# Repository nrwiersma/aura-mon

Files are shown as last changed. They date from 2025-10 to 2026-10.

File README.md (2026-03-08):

<picture>
  <source media="(prefers-color-scheme: dark)" srcset="http://svg.wiersma.co.za/github/project.v2?title=aura mon&tag=energy%20data%20logger&mode=dark">
  <source media="(prefers-color-scheme: light)" srcset="http://svg.wiersma.co.za/github/project.v2?title=aura mon&tag=energy%20data%20logger">
  aura
</picture>

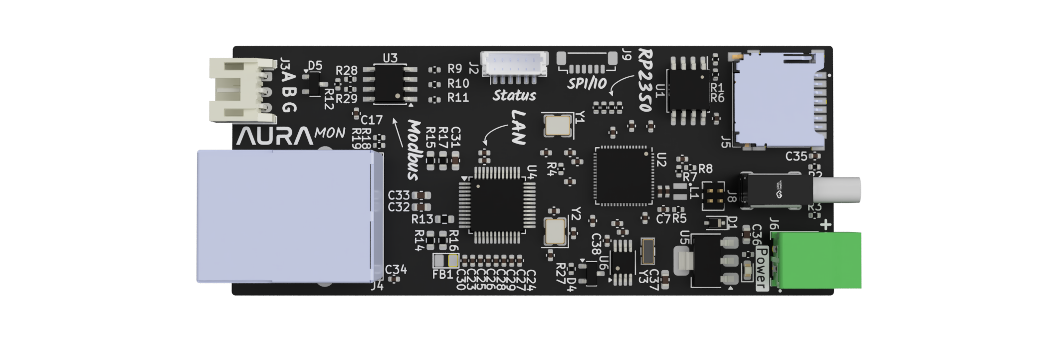
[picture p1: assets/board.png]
board image





`Aura Mon` is an RP2350-based energy data logger built around the tiny [SPM01](https://www.bituo-technik.com/product/spm01-flexible-1pn-63a/) Modbus meter. It samples power data over RS485, stores it on an SD card, and serves a local HTTP API and web UI over Ethernet.

## At a glance

* RP2350 microcontroller
* Modbus RTU over RS485 (SPM01)
* Ethernet for reliable network connectivity
* SD card logging and static web UI hosting
* RTC for timestamped data
* HTTP API with OTA updates and metrics

## System overview

system diagram

## Data flow

data flow

## Why

The goal of this project is to create a reliable and easy-to-use energy data logger that can be used to monitor energy consumption in a home or small business. The SPM01 is a very affordable energy meter that can measure voltage, current, power, energy, and power factor while fitting in tight electrical panels.

## Quick start

1. Assemble the board and connect the SPM01 to the RS485 terminals.
2. Insert an SD card (required for logging).
3. Power the board with a regulated 5V supply on the screw terminals (or via USB-C with the jumper fitted for testing).
4. Connect Ethernet and find the device IP via your router's DHCP lease table.
5. Open `http://<device-ip>` to view the UI and use the API.

## Firmware

The firmware lives in `firmware/` and is written in C++ using the Arduino framework.

* Build/flash instructions: `firmware/FIRMWARE.md`
* HTTP API reference: `firmware/API.md`

### API highlights

* `GET /status` for live readings and runtime stats.
* `GET /energy` for CSV data export.
* `GET /logs` for log streaming.
* `GET`/`POST /config` for device configuration.
* `POST /ota` for firmware updates.
* `GET /metrics` for Prometheus-style metrics.

## Powering

The board can be powered using an external 5V power supply connected to the screw terminals. For testing purposes, it can also be powered via USB-C after connecting the onboard jumper.

## Safety

> [!WARNING]
> This project interfaces with mains-connected equipment. Only install it if you are qualified and follow local electrical safety requirements.

## Project status

The firmware and hardware are still in development and are only tested on the author's hardware. Expect rough edges and please report issues or improvements.

## Changelog

#### v0.1.0

* Initial schematic and board
* Initial firmware with basic functionality to read from the SPM01 and store data on the SD card

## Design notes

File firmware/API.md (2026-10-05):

# AuraMon HTTP API

This document describes the HTTP endpoints exposed by the firmware. All endpoints are served by the device's embedded web server over HTTP.

## Endpoint index

- [`GET /config`](#get-config)
- [`POST /config`](#post-config)
- [`GET /status`](#get-status)
- [`GET /energy`](#get-energy)
- [`POST /device/action`](#post-deviceaction)
- [`GET /logs`](#get-logs)
- [`POST /logs/trunc`](#post-logstrunc)
- [`POST /ota`](#post-ota)
- [`POST /ota/public`](#post-otapublic)
- [`GET /metrics`](#get-metrics)
- [`GET /readyz`](#get-readyz)
- [`GET /livez`](#get-livez)
- [`GET /<path>` (static files)](#get-path-static-files)

## Base

- Base URL: `http://<device-ip>`
- Auth: none
- CORS: enabled

## Common responses

- `200 OK` for successful JSON/plain responses.
- `204 No Content` when there is nothing to return.
- `400 Bad Request` for invalid parameters or invalid JSON.
- `404 Not Found` when a resource does not exist.
- `405 Method Not Allowed` for disallowed methods on static files.
- `408 Request Timeout` when the SD card mutex cannot be acquired.
- `409 Conflict` when a device action is already pending.
- `500 Internal Server Error` for unexpected errors.
- `505 HTTP Version Not Supported` when chunked responses are not available.

## Endpoints

### `GET /config`

Returns the current configuration as JSON.

- Response content type: `application/json`

Example response (shape):
```json
{
  "format": 1,
  "network": {
    "hostname": "aura-mon",
    "ip": "192.168.0.0",
    "gateway": "192.168.0.1",
    "mask": "255.255.255.0",
    "dns": "8.8.8.8"
  },
  "devices": [
    {
      "enabled": true,
      "address": 1,
      "name": "test1",
      "calibration": 1.0,
      "reversed": false
    }
  ]
}
```

### `POST /config`

Updates the configuration. The request body must be JSON.

- Request content type: `application/json`
- Response content type: `text/plain`

Possible error responses:
- `{"error":"No data provided"}`
- `{"error":"Invalid JSON"}`
- `{"error":"Invalid configuration","reason":"..."}`

Example request:
```bash
curl -X POST http://<device-ip>/config \
  -H 'Content-Type: application/json' \
  -d '{"format":1,"network":{"hostname":"aura-mon"},"devices":[]}'
```

### `GET /status`

Returns runtime status and device data.

- Response content type: `application/json`

Response fields:
- `version` string.
- `stats` object: `startTime`, `currentTime`, `runSeconds`, `heapFree`.
- `devices` array: each entry has `name`, `volts`, `amps`, `pf`, `hz`.
- `datalog` object: `firstRev`, `lastRev`, `interval`.
- `network` object: `hostname`, `ip`, `gateway`, `subnet`, `dns`, `mac`.
- `uploaders` array: one entry per configured, enabled uploader (see `POST /config`'s
  `uploaders`), each with:
  - `id`, `type` - matches the uploader's config entry.
  - `state` - `"build"`, `"post"`, or `"wait"`; which step of its request cycle it's
    currently in.
  - `lastSentTS` - datalog timestamp up to which data has been successfully uploaded.
  - `lagSeconds` - how far `lastSentTS` is behind the datalog's most recent record; grows
    while the network is down or the remote endpoint is failing, and shrinks once it
    catches back up.
  - `successTotal`, `failureTotal` - lifetime (since boot) counts of completed requests.
  - `consecutiveFailures` - resets to 0 on the next success; useful for alerting on a
    stuck/misconfigured uploader without tripping on an isolated blip.
  - `lastSuccessAt`, `lastAttemptAt` - unix timestamps, `0` if never.
  - `lastHttpStatus` - HTTP status of the last completed request; `-1` if the last attempt
    failed before a response was received (e.g. could not open/send), `0` if no request has
    completed yet.

### `GET /energy`

Returns energy data as CSV in a chunked response.

- Response content type: `text/plain` (CSV)

Query parameters:
- `start` (required): unix timestamp (seconds).
- `end` (optional): unix timestamp (seconds), defaults to `now`.
- `interval` (optional): seconds, defaults to `5`.

Behavior:
- `start`, `end`, and `interval` are rounded down to the nearest datalog interval.
- If `start >= end` or `interval == 0`, returns `400`.
- Response is capped to 100 rows (`end = start + interval * 100`).
- Returns `204` if there is no data, no enabled devices, or `start` is beyond the last timestamp.

CSV columns:
- `timestamp`
- `Hz`
- For each enabled device: `<name>.V`, `<name>.A`, `<name>.W`, `<name>.Wh`, `<name>.PF`

Example:
```bash
curl "http://<device-ip>/energy?start=1730000000&end=1730003600&interval=60"
```

### `POST /device/action`

Queues a device action.

- Request content type: `application/json`
- Response content type: `application/json`

Request body:
```json
{
  "action": "locate" | "assign",
  "address": 1
}
```

Notes:
- `address` must be in `1..15`.
- Returns `202` with `{"status":"queued"}` when accepted.
- Returns `409` if another action is already pending.

### `GET /logs`

Streams the message log file from the SD card.

- Response content type: `text/plain`
- Query parameters:
  - `start` (optional): byte offset to start streaming from.
  - `limit` (optional): maximum number of bytes to stream.
- Returns `204` when `start` is at or beyond the end of the file, or when `limit=0`.
- Returns `400` for an invalid `start` or `limit` value.
- Returns `404` if the log file is missing.

Example:
```bash
curl "http://<device-ip>/logs?start=1024&limit=4096"
```

### `POST /logs/trunc`

Truncates the message log by keeping content from the last `**** RESTART ****` marker to the end of the file.

- Response content type: `text/plain`
- Uses a temp file and replace flow (`temp -> log`) so truncation is resilient to partial writes.
- Returns `204` on success.
- Returns `404` if the log file is missing.
- Returns `408` if the SD card mutex cannot be acquired.
- Returns `500` for file IO/rename failures.

Example:
```bash
curl -X POST http://<device-ip>/logs/trunc
```

### `POST /ota`

Firmware update via multipart upload.

- Request content type: `multipart/form-data`
- Form field name: `firmware`

Responses:
- `204` on success (device reboots).
- `500` on failure with `{"error":"Update failed","code":<code>}`.

Example:
```bash
curl -X POST http://<device-ip>/ota \
  -F 'firmware=@firmware.bin'
```

### `POST /ota/public`

Upload a static file to the SD card `public/` directory.

- Request content type: `multipart/form-data`
- Form field name: `file`
- Filename must not be empty and must not contain `/` or `\\`.

Responses:
- `204` on success.
- `400` on invalid field name or filename.
- `408` if the SD card mutex cannot be acquired.
- `500` on write failure.

Example:
```bash
curl -X POST http://<device-ip>/ota/public \
  -F 'file=@index.html'
```

### `GET /metrics`

Prometheus-style metrics in text format.

- Response content type: `text/plain`

Exposed metrics:
- `auramon_modbus_errors_total` (counter)
- `auramon_collect_time_seconds_total` (counter)
- `auramon_collect_time_seconds_avg` (gauge)
- `auramon_datalog_read_io` (counter)
- `auramon_datalog_write_io` (counter)
- `auramon_datalog_write_time_seconds_total` (counter)
- `auramon_datalog_cache_hit` (counter)
- `auramon_datalog_write_errors_total` (counter)
- `auramon_datalog_queue_depth` (gauge)
- `auramon_datalog_queue_full_total` (counter)
- `auramon_datalog_records_dropped_total` (counter)
- `auramon_uploader_requests_total{id,type}` (counter) - total successful upload requests.
- `auramon_uploader_errors_total{id,type}` (counter) - total failed upload attempts (network
  or non-2xx response).
- `auramon_uploader_consecutive_failures{id,type}` (gauge) - current run of consecutive
  failed attempts, reset on the next success.
- `auramon_uploader_lag_seconds{id,type}` (gauge) - how far behind the uploader is from the
  most recently logged record.
- `auramon_uploader_last_success_timestamp_seconds{id,type}` (gauge) - unix timestamp of the
  last successful upload, `0` if never.
- `auramon_uploader_last_http_status{id,type}` (gauge) - HTTP status of the last completed
  request; `-1` if it failed before a response was received, `0` if none has completed yet.

### `GET /readyz`

Returns `200` with an empty body.

### `GET /livez`

Returns `200` with an empty body.

### `GET /<path>` (static files)

Any other `GET` request serves files from the SD card `public/` directory.

Behavior:
- `/` maps to `/index.html`.
- If a `.gz` version exists, it is served with `Content-Encoding: gzip`.
- Directories return `403`.
- Unknown paths return `404`.

Common content types:
- `.html` -> `text/html`
- `.css` -> `text/css`
- `.js` -> `application/javascript`
- `.json` -> `application/json`
- `.png` -> `image/png`
- `.jpg`/`.jpeg` -> `image/jpeg`
- `.svg` -> `image/svg+xml`

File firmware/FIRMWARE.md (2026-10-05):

# Firmware Architecture

The firmware runs on an RP2040 dual-core microcontroller. Each core has a dedicated role: **Core 0 (Control Plane)** handles networking, the web API, and system housekeeping, while **Core 1 (Data Plane)** handles real-time energy data collection and storage.

```mermaid
flowchart TD
    subgraph BOOT["Boot Sequence (Core 0)"]
        direction TB
        B1[Init Serial & LEDs] --> B2[Init SD Card]
        B2 --> B3[Init RTC & set system time]
        B3 --> B4[Load config & sync device info]
        B4 --> B5[Init Ethernet / W5500]
        B5 --> B6[Init Datalog]
        B6 --> B7[Init Modbus RTU / RS-485]
        B7 --> B8[Setup Web API & HTTP server]
        B8 --> B9[Register tasks & signal Core 1 via FIFO]
    end

    subgraph C0["Core 0 — Control Plane"]
        direction TB
        L0A[server.handleClient\nServe HTTP API requests]
        L0B[handleButtonPress\nDebounce button & queue addDeviceFromButton]
        L0C[c0Queue.runNextTask]

        T0A["⏱ timeSync  · 60s\nNTP sync, update RTC\nReboot after 42 days"]
        T0B["⏱ checkEthernet  · 1s\nMonitor link & IP\nReboot after 60 min offline"]
        T0C["⏱ syncState  · 1s\nCheck SD & Ethernet\nUpdate LED  🔴 · 🟠 · 🟢"]
        T0D["▶ addDeviceFromButton  · on demand\nAssign free Modbus address\nSave config to SD"]
        T0E["⏱ writeLogData  · 100ms idle\nPop queued records\nWrite record to SD datalog"]
        T0F["⏱ syncUploaders  · 1s\nInstantiate/stop Uploader objects\nfrom config.json's uploaders[]"]
        T0G["▶ Uploader.dispatch  · per uploader\nBuild → Post → Wait state machine\nAsyncHTTP (RPAsyncTCP), non-blocking"]

        L0C --> T0A & T0B & T0C & T0D & T0E & T0F & T0G
    end

    subgraph C1["Core 1 — Data Plane"]
        direction TB
        S1[Wait for FIFO signal] --> S2[initLogData & start watchdog 800ms]

        L1A["collect()  · each cycle\nPoll all devices over Modbus RTU\nDecode V, A, W, VA, PF, Hz\nUpdate metrics"]
        L1B[c1Queue.runNextTask\nKick watchdog]

        T1A["⏱ logData  · per interval\nAccumulate Wh / VAh / VoltHrs\nQueue record for Core 0"]
        T1B["⏱ syncDevices  · 1s\nSync device info, actions\n& live readings via mutexes"]
        T1C["⏱ deviceActionTask  · 1s\nLocate: flash device LED\nAssign: set Modbus address"]

        S2 --> L1A --> L1B
        L1B --> T1A & T1B & T1C
    end

    BOOT --> C0 & C1
```

## Core Responsibilities

| | Core 0 | Core 1 |
|---|---|---|
| **Main loop focus** | HTTP request handling & button debounce | Energy data collection via Modbus (1 s cycle) |
| **Scheduled tasks** | `timeSync`, `checkEthernet`, `syncState`, `writeLogData`, `syncUploaders`, one `Uploader::dispatch` per configured uploader | `logData`, `syncDevices`, `deviceActionTask` |
| **On-demand tasks** | `addDeviceFromButton` (button press) | — |
| **Watchdog** | — | 800 ms watchdog, kicked each collection cycle |
| **LED control** | `syncState` sets colour, `Ticker` blinks at 1 Hz | — |

## Task Priorities (higher = runs first when multiple tasks are due)

| Task | Core | Priority |
|---|---|---|
| `logData` | 1 | 7 |
| `syncDevices` | 1 | 6 |
| `writeLogData` | 0 | 6 |
| `timeSync` | 0 | 5 |
| `deviceActionTask` | 1 | 5 |
| `checkEthernet` | 0 | 5 |
| `syncState` | 0 | 4 |
| `syncUploaders` | 0 | 3 |
| `Uploader::dispatch` (each uploader) | 0 | 2 |

## Data Log Record Queue

`logData` on Core 1 accumulates energy readings, but does not touch the SD card. Once an
interval completes, the record is copied onto a fixed size FIFO queue (`logQueue`, 8 records)
and `writeLogData` on Core 0 pops it and writes it to the data log. This keeps SD card IO,
which can block for tens of milliseconds, off the collection core.

- If the queue is full, `logData` retries on the next cycle rather than dropping the record,
  so the log slips but no data is lost.
- Records are queued and written in timestamp order, which the data log requires.
- A record that fails to write is retried up to 5 times, then dropped so it cannot block the
  records behind it.
- On a controlled reboot, the queue is drained before the data log is closed.

## Uploaders (InfluxDB2/3, Home Assistant, ...)

`Uploader` (`src/uploader/uploader.h/.cpp`) is the base class for Core0 tasks that push data
log records to a remote service. `UploaderConfig` (`src/config.h`) is its persisted,
user-editable counterpart: an entry in config.json's `uploaders` array (`id`, `type`,
`enabled`, `interval`, and a free-form `settings` object whose schema is owned by the
concrete uploader type). `uploader_registry.cpp` is the only code that creates or stops
`Uploader` instances, reconciling `uploaderConfigs[]` with live instances whenever the config
changes (`syncUploaders`, mirroring `syncDevices`'s `devicesChanged` pattern) — concrete
uploader types are registered there as they are implemented.

- `InfluxDB2Uploader` (`src/uploader/influxdb2_uploader.h/.cpp`, `type: "influxdb2"`) writes
  one line-protocol point per enabled, named device per interval (plus one for mains
  frequency) to an InfluxDB 2.x bucket via `/api/v2/write`. Settings: `url`, `org`, `bucket`,
  `token`, optional `measurement` (default `"aura-mon"`). Its settings parsing and
  line-protocol formatting are pulled out into `src/uploader/influxdb2_format.h/.cpp`, which
  has no HTTP/xbuf/data-log dependencies and is covered by native unit tests
  (`test/test_influxdb2`); the surrounding HTTP/data-log glue in `influxdb2_uploader.cpp`
  follows `Uploader` itself in being hardware-only and not natively tested.
- `HomeAssistantUploader` (`src/uploader/homeassistant_uploader.h/.cpp`, `type:
  "homeassistant"`) posts one JSON payload per interval - mains frequency plus one entry per
  enabled, named device - to a Home Assistant webhook (`<url>/api/webhook/<webhook_id>`).
  Settings: `url`, `webhook_id`. Unlike InfluxDB2's point-per-reading model, the payload
  carries the whole interval as a single object: `{"ts", "hz", "devices": [{"name", "volts",
  "amps", "watts", "wh", "pf"}, ...]}`, where `wh` is the energy consumed during that interval
  (not a running total), matching the existing pull-based `/energy` semantics so the Home
  Assistant component can accumulate it itself. Its settings parsing and payload building are
  pulled out into `src/uploader/homeassistant_format.h/.cpp` (no HTTP/xbuf/data-log
  dependencies, covered by native unit tests in `test/test_homeassistant`); the hardware glue
  in `homeassistant_uploader.cpp` serializes the built `JsonDocument` straight into the
  request body via ArduinoJson's `Print`-based `serializeJson`.

Each `Uploader` runs as its own lowest-priority Core0 task, built on `lib/AsyncHTTP`
(`asyncHTTPrequest` ported onto `RPAsyncTCP`) so a request in flight never blocks anything
else: `dispatch()` is a non-blocking `Build → Post → Wait` state machine that returns almost
immediately every tick.

- **No data is lost on a network outage.** The data log already retains up to ~180 days of
  history on SD; an uploader only tracks how far it has gotten (`_lastSentTS`), persisted to
  `aura-mon/uploaders/<id>.state`. While the link is down (`eth.isLinked()`/`connected()`
  checked every `Build`), the uploader simply waits and retries — it never advances past data
  it hasn't confirmed as sent, and a reboot resumes from the saved position rather than
  replaying the whole log or skipping ahead.
- **Never blocks SD or networking.** Scheduled at the lowest Core0 priority (below
  `writeLogData`, `checkEthernet`, and `syncState`), so it only runs when nothing more
  important is due, and each state transition does O(1) non-blocking work.
- **Stopping is self-serviced.** The task queue has no cancel primitive, so a disabled or
  misconfigured uploader is told to stop (`requestStop()`); the registry drops its own
  pointer immediately, and the instance deregisters and frees itself (`delete this; return
  0;`) the next time its already-scheduled task runs.
- **Health is observable.** Each `Uploader` tracks success/failure counts, consecutive
  failures, last HTTP status, and last success/attempt timestamps (`recordResult()`,
  read-only accessors on `Uploader`); `forEachUploader()` (`uploader_registry.h`) lets
  `api.cpp` surface these, plus `lastSentTS`/`lagSeconds` (how far behind the datalog's head
  it is) and its current state machine step, in both `GET /status` (`uploaders` array) and
  `GET /metrics` (`auramon_uploader_*` series, labelled `id`/`type`) — see `API.md`. No
  locking is needed since `dispatch()` and the web server both run on Core0's single
  cooperative loop.

## Hardware Peripherals

| Peripheral | Interface | Used By |
|---|---|---|
| W5500 Ethernet | SPI | Control Plane — HTTP server, NTP, link monitoring |
| RS-485 / Modbus RTU | Serial1 | Data Plane — device polling & address assignment |
| SD Card | SDIO (`sdMu`) | Control Plane — config r/w & datalog writes |
| PCF85063A RTC | I²C / Wire1 | Boot — set system clock |
| LED (Red / Green) | GPIO 10 / 11 | Control Plane — `syncState` sets colour, `Ticker` blinks at 1 Hz |
| Physical Button | GPIO 3 | Control Plane — triggers `addDeviceFromButton` on press |

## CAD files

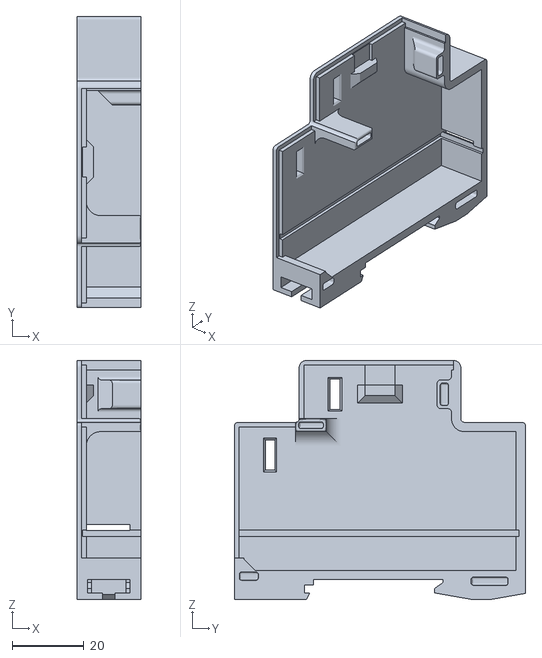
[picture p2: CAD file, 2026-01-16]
models/Base Right.stl
17.9 x 81.0 x 66.5

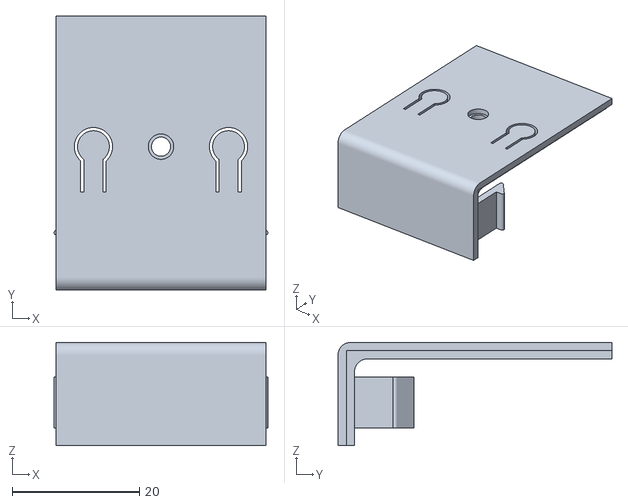
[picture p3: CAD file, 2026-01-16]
models/Face Top.stl
33.5 x 43.0 x 16.2

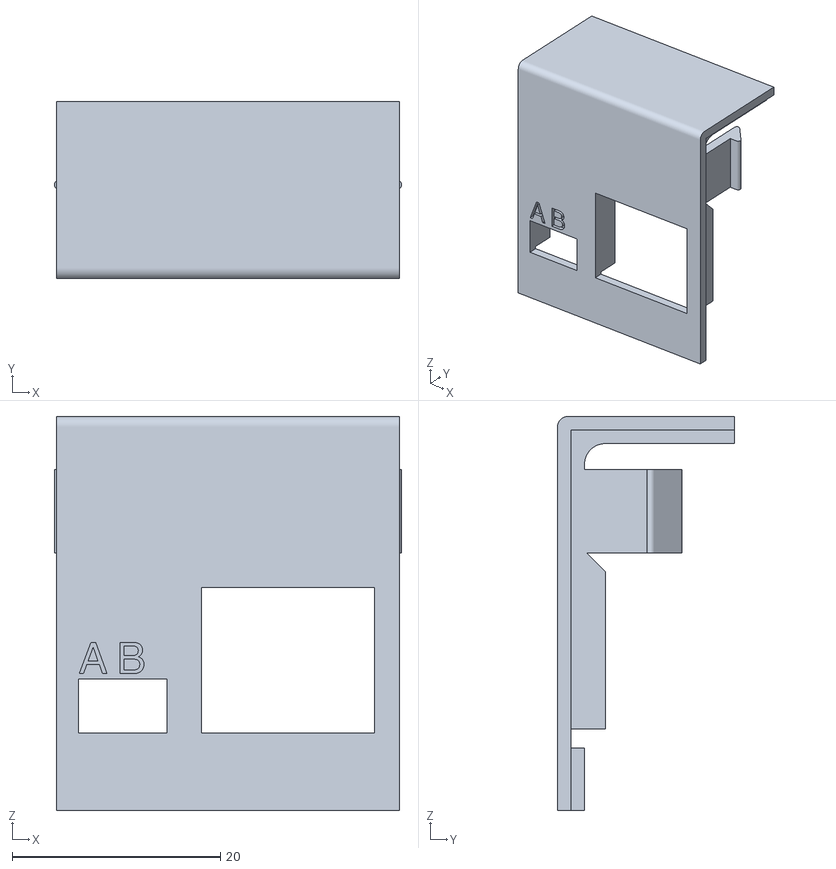
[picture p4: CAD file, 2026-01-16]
models/Face Bottom.stl
33.3 x 17.0 x 37.8

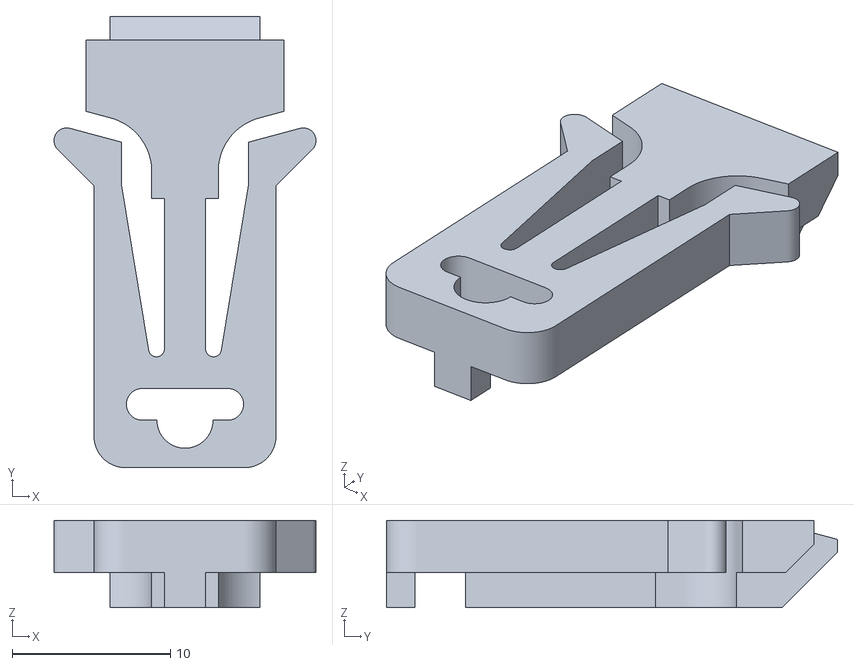
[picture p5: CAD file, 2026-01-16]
models/Clip.stl
16.5 x 28.5 x 5.50

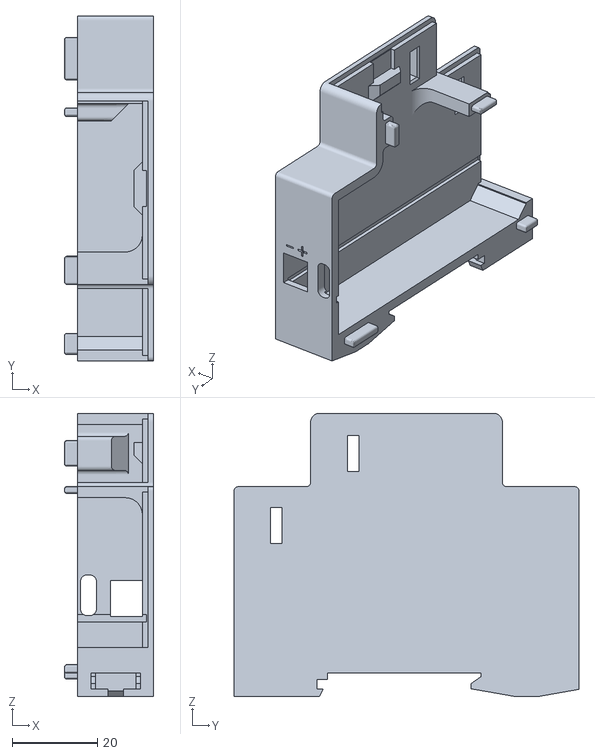
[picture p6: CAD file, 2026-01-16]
models/Base Left.stl
20.9 x 81.0 x 66.5

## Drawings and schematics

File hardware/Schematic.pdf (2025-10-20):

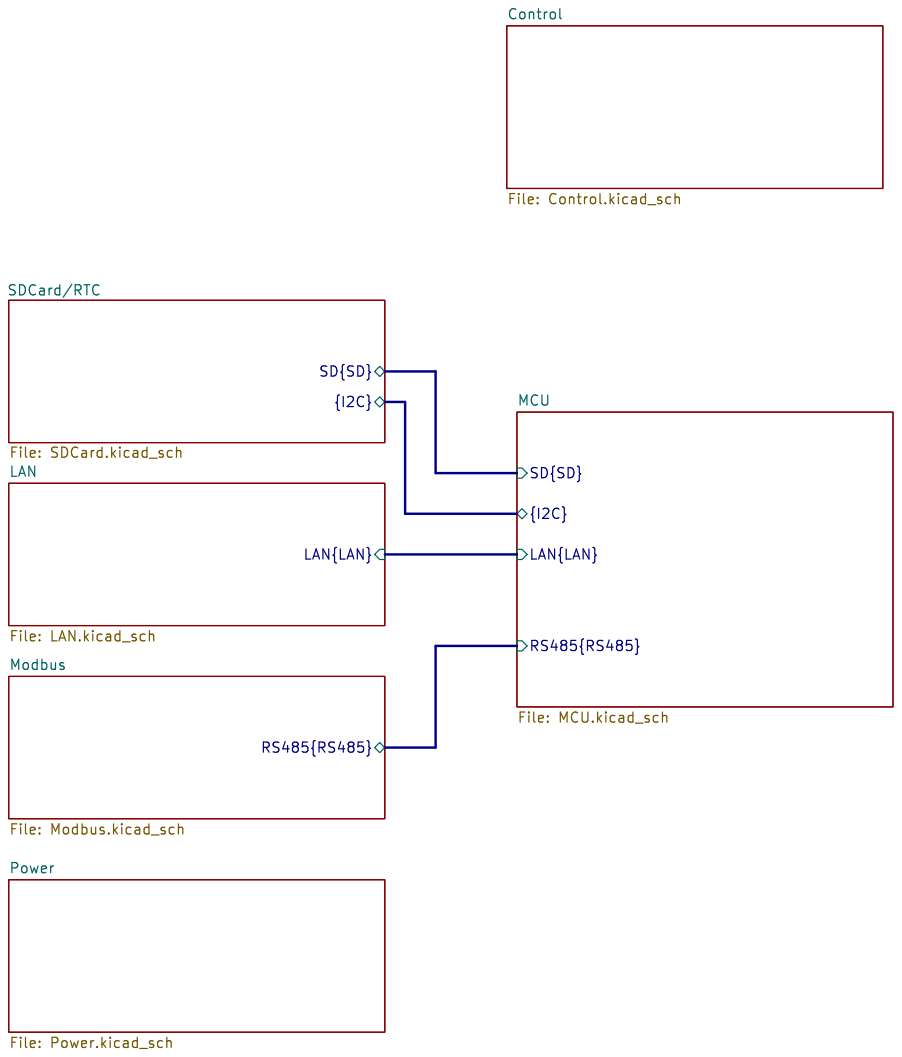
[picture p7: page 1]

File: MCU.kicad_sch Control File: Control.kicad_sch SD{SD}

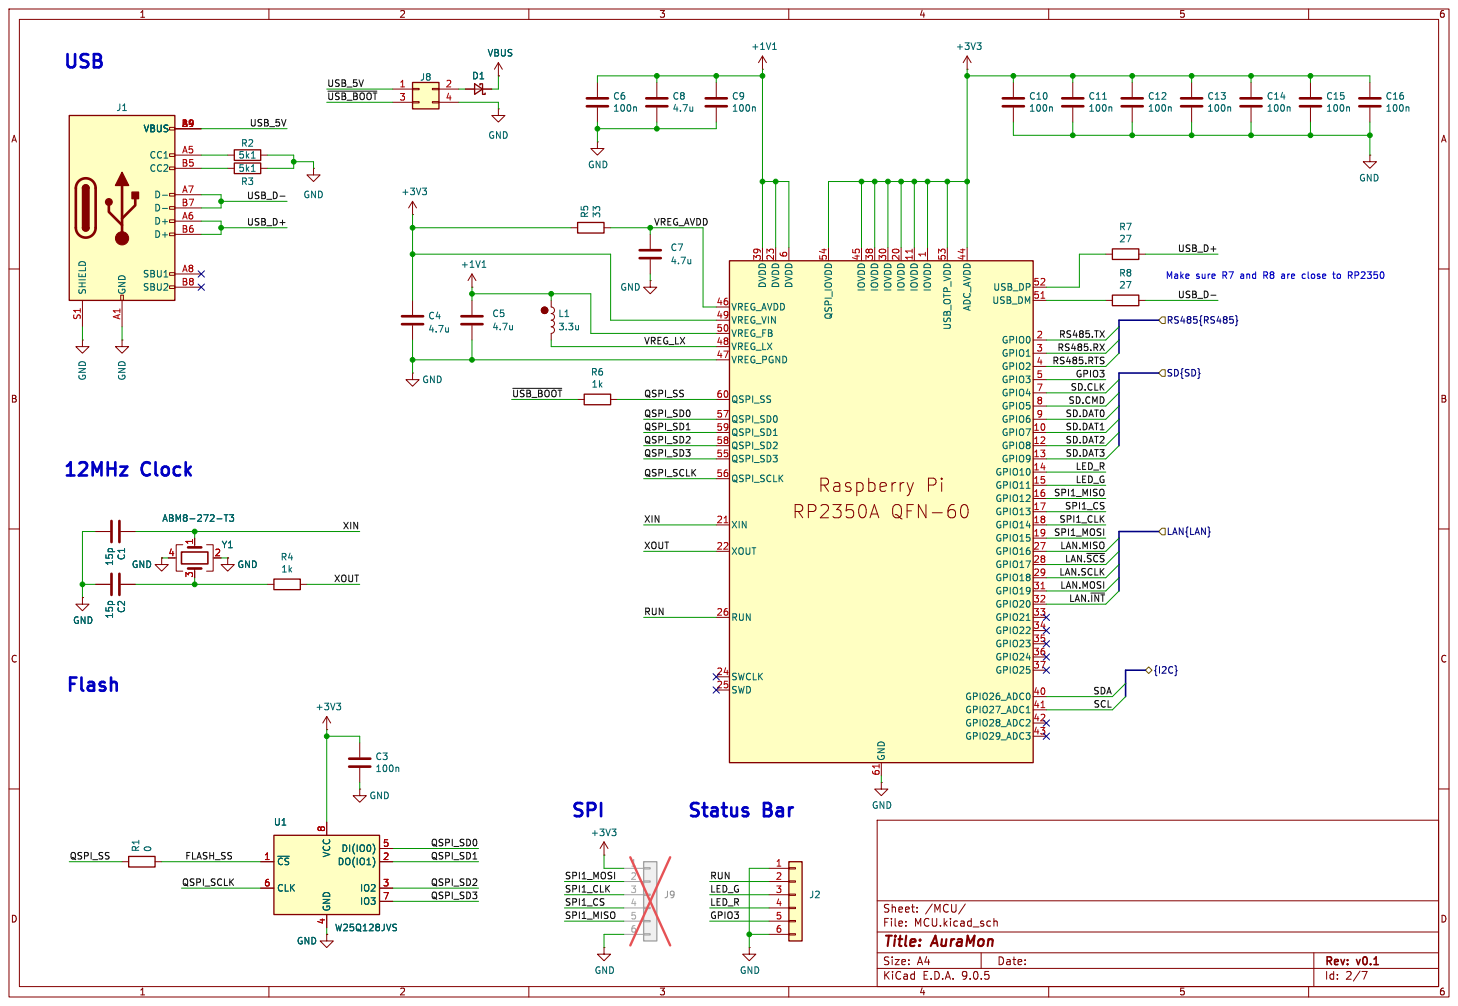
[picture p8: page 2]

6 QSPI_IOVDD 54 IOVDD 45 IOVDD 38 GND 61 IOVDD 30 IOVDD 20 IOVDD 11 IOVDD

SPI1_MOSI LAN.~{SCS} LAN.MISO
LAN.~{INT} SDA

File: MCU.kicad_sch Sheet: /MCU/
Id: 2/7 Title: AuraMon

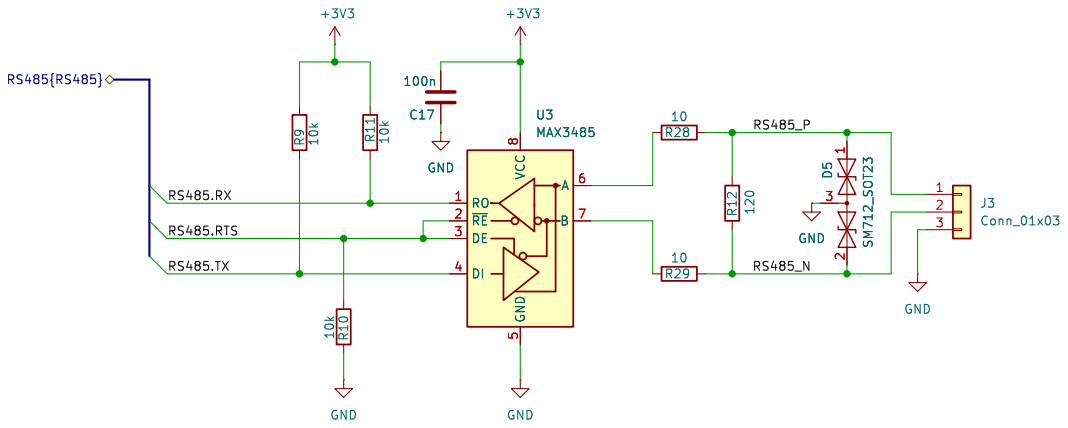
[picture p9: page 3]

2 U3 MAX3485 RO 1 ~{RE} 2 DE 3 DI 4 VCC

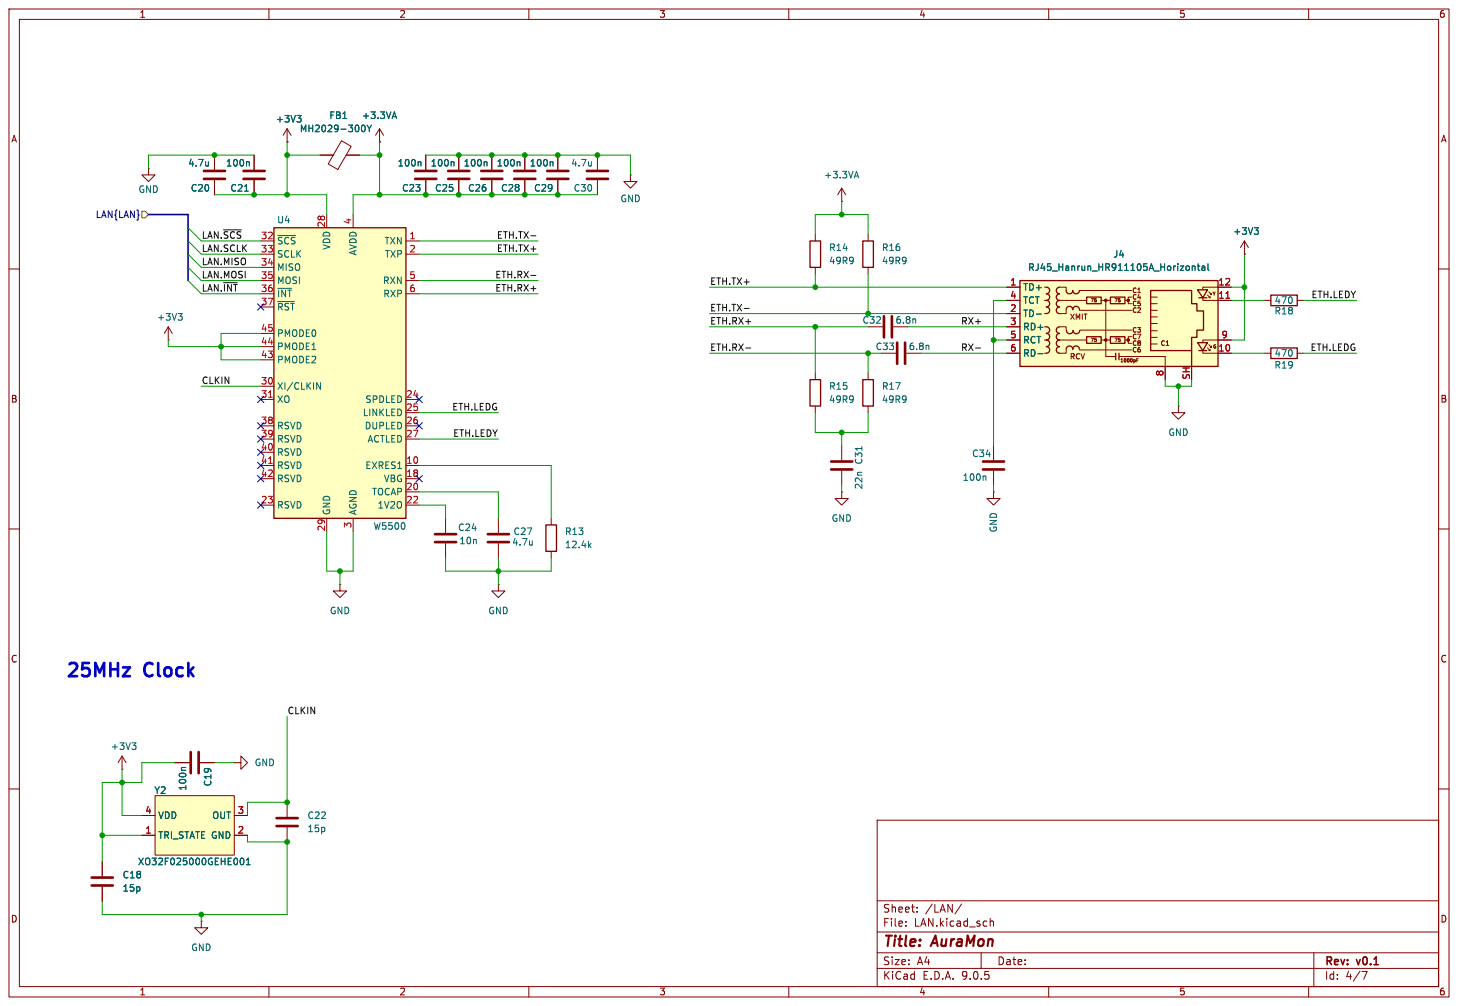
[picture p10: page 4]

LAN.MOSI LAN.~{INT} CLKIN

3 TXN 1 TXP 2 RXN 5 RXP 6 SPDLED 24

ETH.RX+ ETH.LEDY

File: LAN.kicad_sch Sheet: /LAN/
Id: 4/7 Title: AuraMon

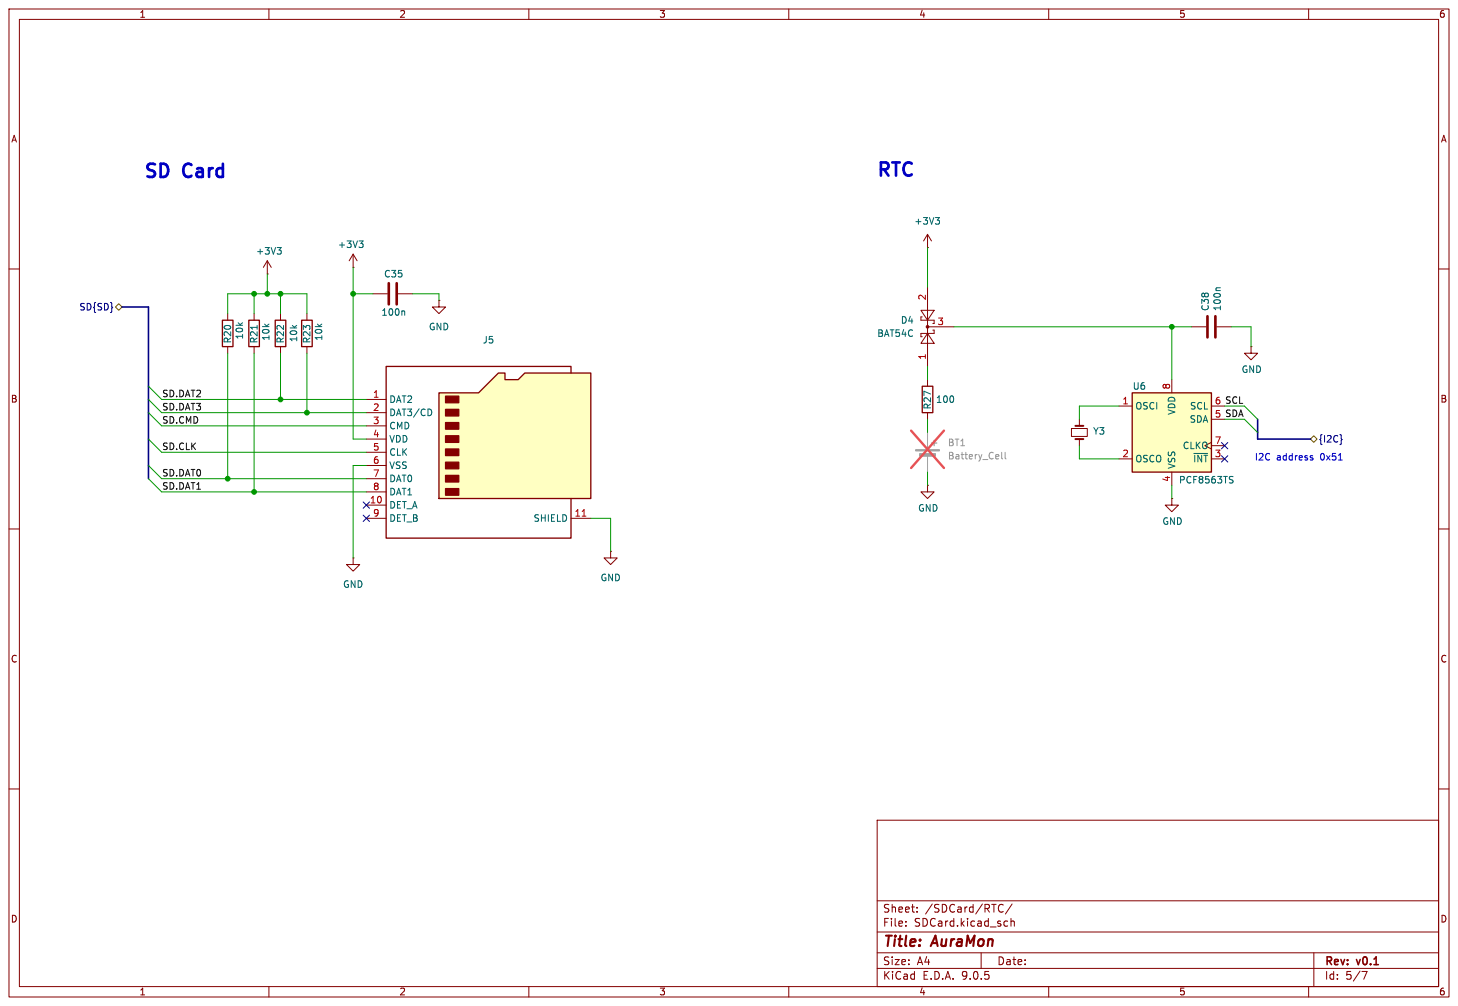
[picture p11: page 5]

4 SCL 6 SDA 5 CLKO 7 ~{INT}3 U6 PCF8563TS GND

File: SDCard.kicad_sch Sheet: /SDCard/RTC/
Id: 5/7 Title: AuraMon

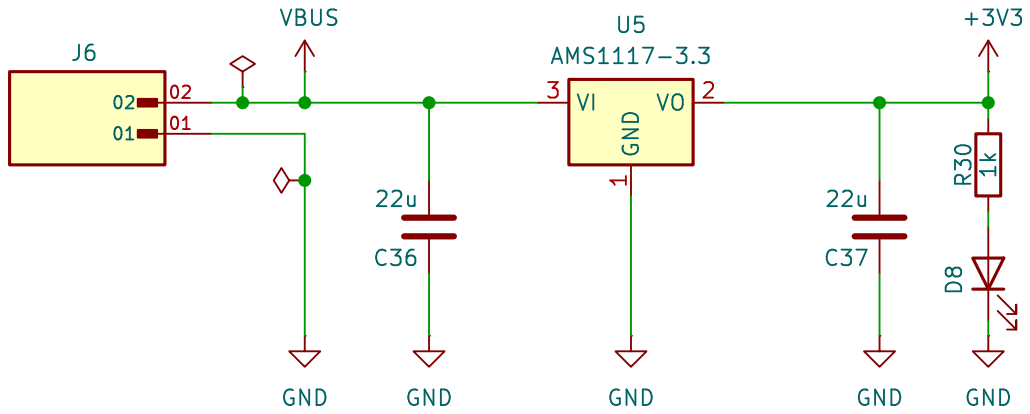
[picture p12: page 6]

File: Power.kicad_sch Sheet: /Power/
Id: 6/7 Title: AuraMon

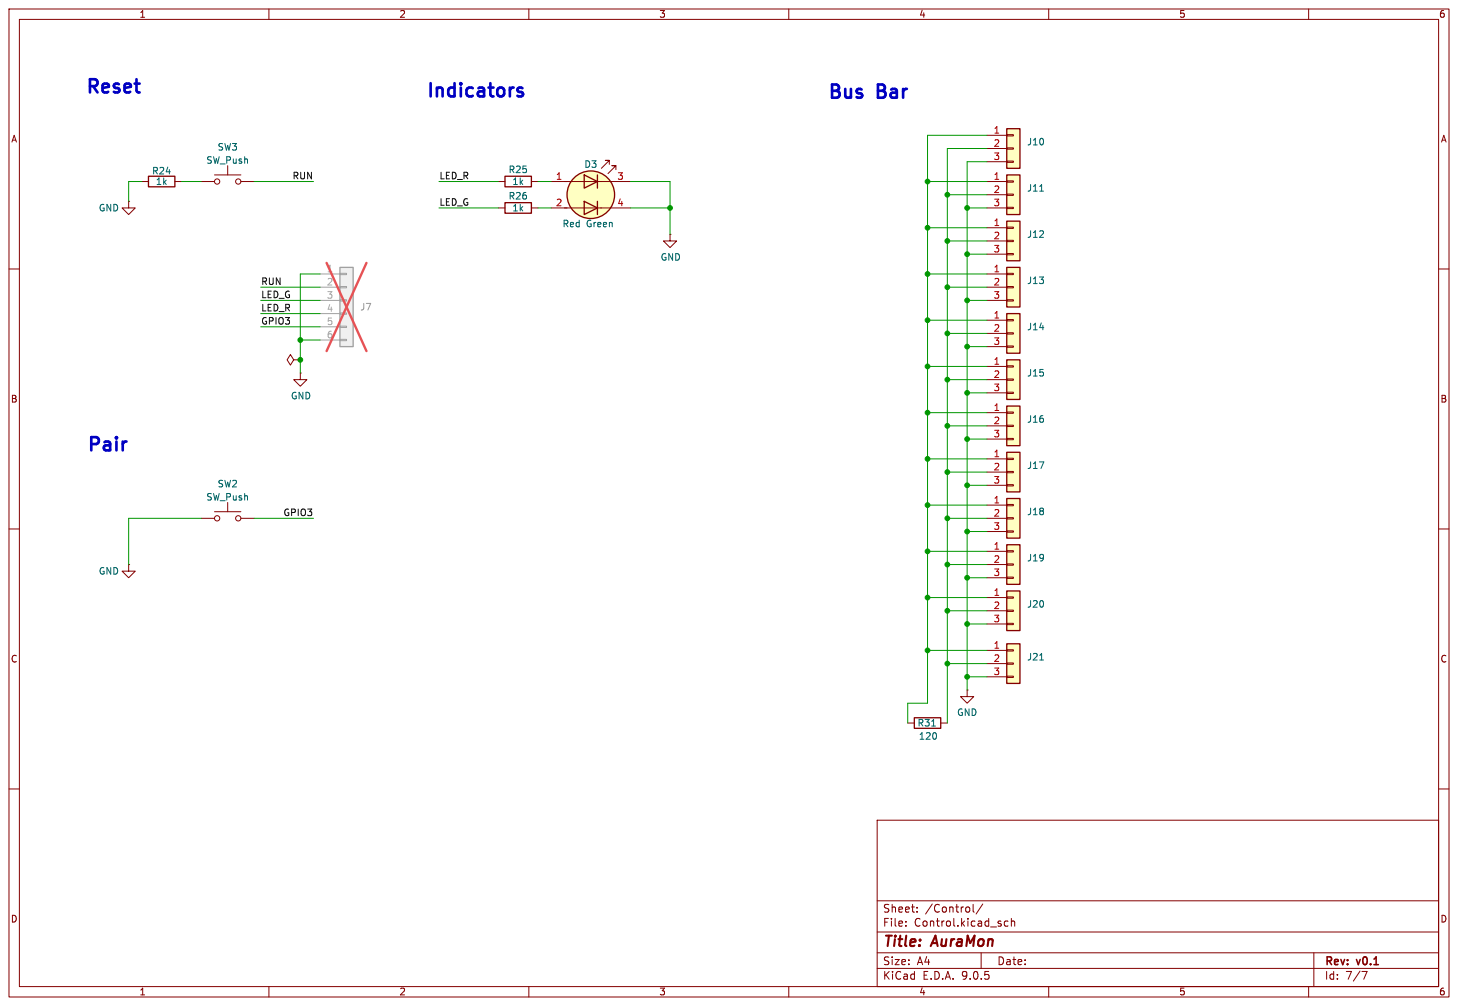
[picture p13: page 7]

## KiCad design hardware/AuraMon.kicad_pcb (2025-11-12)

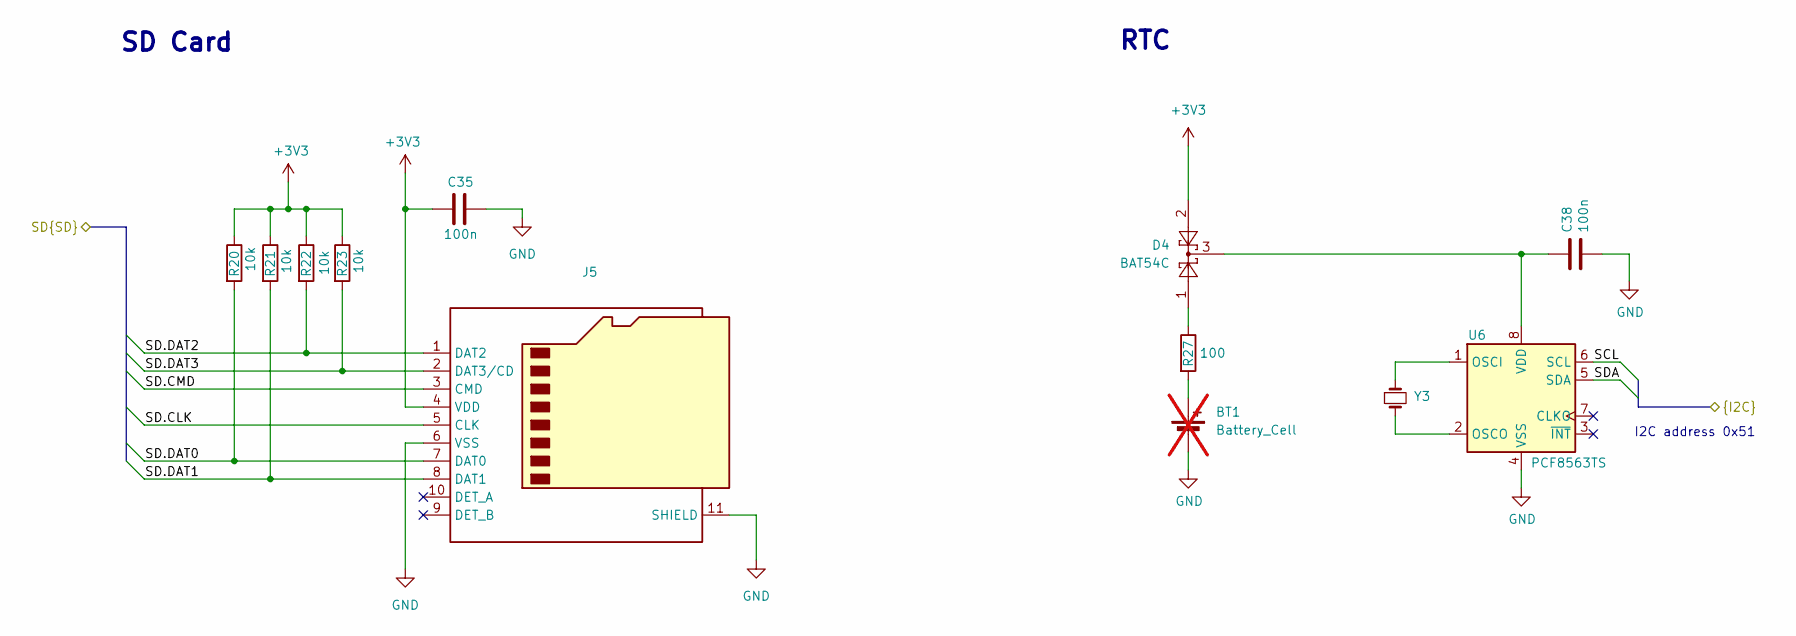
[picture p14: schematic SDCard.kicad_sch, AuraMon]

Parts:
BT1: Battery_Cell; BatteryHolder_Keystone_1060_1x2032; not fitted
C35, C38: 100n; C_0402_1005Metric; MPN CL05B104KO5NNNC; JLCPCB Part # C1525
D4: BAT54C; SOT-23; MPN BAT54C-7-F; JLCPCB Part # C134405
J5: Micro_SD_Card_Det_Hirose_DM3AT; AMPHENOL_1140084168; MPN 114-00841-68; JLCPCB Part # C3195424
R20, R21, R22, R23: 10k; R_0402_1005Metric; MPN RC0402JR-0710KL; JLCPCB Part # C60489
R27: 100; R_0402_1005Metric; MPN RC0402FR-07100RL; JLCPCB Part # C106232
U6: PCF8563TS; MSOP-8_3x3mm_P0.65mm; MPN PCF85063ATT/AJ; JLCPCB Part # C165608
Y3: X321532768KGD2SI; Crystal_SMD_3215-2Pin_3.2x1.5mm; MPN X321532768KGD2SI; JLCPCB Part # C620155

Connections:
+3V3: C35.2, D4.2, J5.4 (VDD), R20.1, R21.1, R22.1, R23.1; also elsewhere on the board
/MCU/SCL: U6.6 (SCL); also elsewhere on the board
/MCU/SD.CLK: J5.5 (CLK); also elsewhere on the board
/MCU/SD.CMD: J5.3 (CMD); also elsewhere on the board
/MCU/SD.DAT0: J5.7 (DAT0), R20.2; also elsewhere on the board
/MCU/SD.DAT1: J5.8 (DAT1), R21.2; also elsewhere on the board
/MCU/SD.DAT2: J5.1 (DAT2), R22.2; also elsewhere on the board
/MCU/SD.DAT3: J5.2 (DAT3/CD), R23.2; also elsewhere on the board
/MCU/SDA: U6.5 (SDA); also elsewhere on the board
GND: BT1.2 (-), C35.1, C38.2, J5.6 (VSS), J5.11 (SHIELD), U6.4 (VSS); also elsewhere on the board
unnamed: BT1.1 (+), R27.2
unnamed: D4.1, R27.1
unnamed: U6.1 (OSCI), Y3.1
unnamed: U6.2 (OSCO), Y3.2
unnamed: C38.1, D4.3, U6.8 (VDD)

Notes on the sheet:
I2C address 0x51
RTC
SD Card

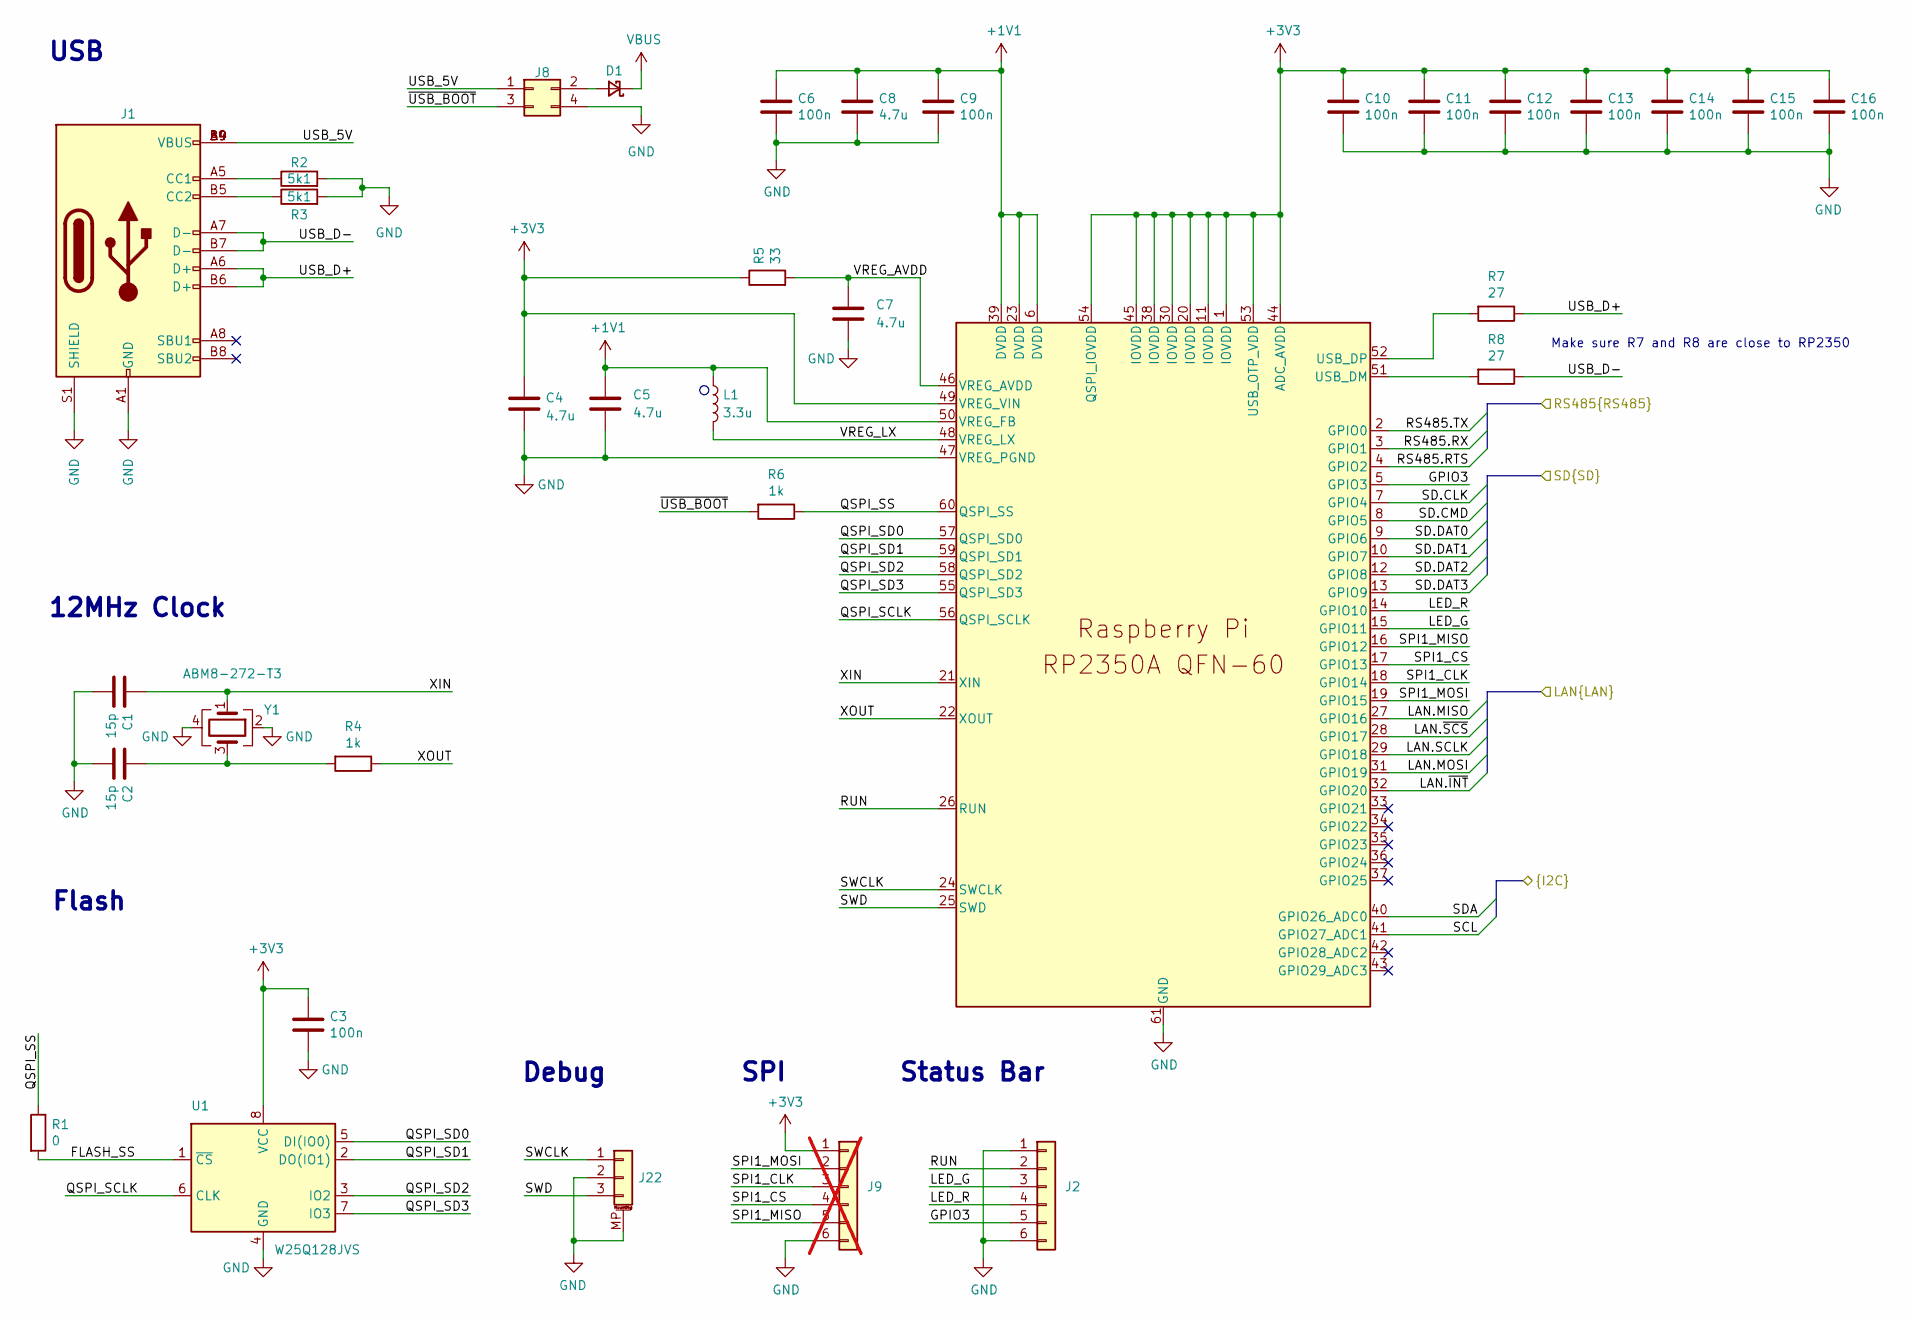
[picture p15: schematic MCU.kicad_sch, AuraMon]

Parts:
C1, C2: 15p; C_0402_1005Metric; MPN CL05C150JB5NNNC; JLCPCB Part # C86285
C3, C6, C9, C10, C11, C12, C13, C14, C15, C16: 100n; C_0402_1005Metric; MPN CL05B104KO5NNNC; JLCPCB Part # C1525
C4, C5: 4.7u; C_0402_1005Metric_small_pads; MPN CL05A475MO5NUNC; JLCPCB Part # C318563
C7, C8: 4.7u; C_0402_1005Metric; MPN CL05A475MO5NUNC; JLCPCB Part # C318563
D1: D_Schottky_Small; D_SOD-323; MPN BAT760-7; JLCPCB Part # C124187
J1: USB_C_Receptacle_USB2.0_16P; USB-C-SMD_TYPEC-305-ACP16H458; MPN TYPEC-305-ACP16H458; JLCPCB Part # C5454943
J2: Conn_01x06; JST_SH_BM06B-SRSS-TB_1x06-1MP_P1.00mm_Vertical; MPN BM06B-SRSS-TB(LF)(SN); JLCPCB Part # C160392
J8: Conn_02x02_Odd_Even; PinHeader_2x02_P1.27mm_Vertical; MPN DW127R-22-04-23; JLCPCB Part # C2935950
J9: Conn_01x06; JST_SUR_BM06B-SURS-TF_1x06-1MP_P0.80mm_Vertical; not fitted
J22: SM03B-SRSS-TB; JST_SH_SM03B-SRSS-TB_1x03-1MP_P1.00mm_Horizontal
L1: 3.3u; L_pol_2016; MPN AOTA-B201610S3R3-101-T; JLCPCB Part # C42411119
R1: 0; R_0402_1005Metric; MPN RC0402JR-070RL; JLCPCB Part # C60485
R2, R3: 5k1; R_0402_1005Metric; MPN RC0402FR-075K1L; JLCPCB Part # C105872
R4, R6: 1k; R_0402_1005Metric; MPN RC0402FR-071KL; JLCPCB Part # C106235
R5: 33; R_0402_1005Metric; MPN RC0402FR-0733RL; JLCPCB Part # C138002
R7, R8: 27; R_0402_1005Metric; MPN RC0402FR-0727RL; JLCPCB Part # C138021
U1: W25Q128JVS; SOIC-8_5.23x5.23mm_P1.27mm; MPN W25Q128JVSIQ; JLCPCB Part # C97521
U2: RP2350A; QFN-60_7X7_RPI; MPN RP2350A; JLCPCB Part # C42411118
Y1: ABM8-272-T3; Crystal_SMD_3225-4Pin_3.2x2.5mm; MPN ABM8-272-T3; JLCPCB Part # C20625731

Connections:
+1V1: C5.1, C6.1, C8.1, C9.1, L1.1, U2.6 (DVDD), U2.23 (DVDD), U2.39 (DVDD), U2.50 (VREG_FB)
+3V3: C3.1, C4.1, C10.1, C11.1, C12.1, C13.1, C14.1, C15.1, C16.1, J9.1, R5.1, U1.8 (VCC), U2.1 (IOVDD), U2.11 (IOVDD), U2.20 (IOVDD), U2.30 (IOVDD), U2.38 (IOVDD), U2.44 (ADC_AVDD), U2.45 (IOVDD), U2.49 (VREG_VIN), U2.53 (USB_OTP_VDD), U2.54 (QSPI_IOVDD); also elsewhere on the board
/LAN/LAN.MISO: U2.27 (GPIO16); also elsewhere on the board
/LAN/LAN.MOSI: U2.31 (GPIO19); also elsewhere on the board
/LAN/LAN.SCLK: U2.29 (GPIO18); also elsewhere on the board
/LAN/LAN.~INT: U2.32 (GPIO20); also elsewhere on the board
/LAN/LAN.~SCS: U2.28 (GPIO17); also elsewhere on the board
/MCU/FLASH_SS: R1.2, U1.1 (~CS)
/MCU/GPIO3: J2.5, U2.5 (GPIO3)
/MCU/LED_G: J2.3, U2.15 (GPIO11)
/MCU/LED_R: J2.4, U2.14 (GPIO10)
/MCU/QSPI_SCLK: U1.6 (CLK), U2.56 (QSPI_SCLK)
/MCU/QSPI_SD0: U1.5 (DI(IO0)), U2.57 (QSPI_SD0)
/MCU/QSPI_SD1: U1.2 (DO(IO1)), U2.59 (QSPI_SD1)
/MCU/QSPI_SD2: U1.3 (IO2), U2.58 (QSPI_SD2)
/MCU/QSPI_SD3: U1.7 (IO3), U2.55 (QSPI_SD3)
/MCU/QSPI_SS: R1.1, R6.1, U2.60 (QSPI_SS)
/MCU/RS485.RTS: U2.4 (GPIO2); also elsewhere on the board
/MCU/RS485.RX: U2.3 (GPIO1); also elsewhere on the board
/MCU/RS485.TX: U2.2 (GPIO0); also elsewhere on the board
/MCU/RUN: J2.2, U2.26 (RUN)
/MCU/SCL: U2.41 (GPIO27_ADC1); also elsewhere on the board
/MCU/SD.CLK: U2.7 (GPIO4); also elsewhere on the board
/MCU/SD.CMD: U2.8 (GPIO5); also elsewhere on the board
/MCU/SD.DAT0: U2.9 (GPIO6); also elsewhere on the board
/MCU/SD.DAT1: U2.10 (GPIO7); also elsewhere on the board
/MCU/SD.DAT2: U2.12 (GPIO8); also elsewhere on the board
/MCU/SD.DAT3: U2.13 (GPIO9); also elsewhere on the board
/MCU/SDA: U2.40 (GPIO26_ADC0); also elsewhere on the board
/MCU/SPI1_CLK: J9.3, U2.18 (GPIO14)
/MCU/SPI1_CS: J9.4, U2.17 (GPIO13)
/MCU/SPI1_MISO: J9.5, U2.16 (GPIO12)
/MCU/SPI1_MOSI: J9.2, U2.19 (GPIO15)
/MCU/SWCLK: J22.1, U2.24 (SWCLK)
/MCU/SWD: J22.3, U2.25 (SWD)
/MCU/USB_5V: J1.A4 (VBUS), J1.A9 (VBUS), J1.B4 (VBUS), J1.B9 (VBUS), J8.1
/MCU/USB_D+: J1.A6 (D+), J1.B6 (D+), R7.1
/MCU/USB_D-: J1.A7 (D-), J1.B7 (D-), R8.1
/MCU/VREG_AVDD: C7.1, R5.2, U2.46 (VREG_AVDD)
/MCU/VREG_LX: L1.2, U2.48 (VREG_LX)
/MCU/XIN: C1.1, U2.21 (XIN), Y1.1
/MCU/XOUT: R4.1, U2.22 (XOUT)
/MCU/~USB_BOOT: J8.3, R6.2
GND: C1.2, C2.2, C3.2, C4.2, C5.2, C6.2, C7.2, C8.2, C9.2, C10.2, C11.2, C12.2, C13.2, C14.2, C15.2, C16.2, J1.A1 (GND), J1.A12 (GND), J1.B1 (GND), J1.B12 (GND), J1.S1 (SHIELD), J2.1, J2.6, J8.4, J9.6, J22.2, J22.MP (MountPin), R2.2, R3.2, U1.4 (GND), U2.47 (VREG_PGND), U2.61 (GND), Y1.2, Y1.4; also elsewhere on the board
unnamed: C2.1, R4.2, Y1.3
unnamed: D1.2 (A), J8.2
unnamed: J1.A5 (CC1), R2.1
unnamed: J1.B5 (CC2), R3.1
unnamed: R8.2, U2.51 (USB_DM)
unnamed: R7.2, U2.52 (USB_DP)
VBUS: D1.1 (K); also elsewhere on the board

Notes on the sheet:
Debug
Status Bar
USB
Make sure R7 and R8 are close to RP2350
SPI
12MHz Clock
Flash

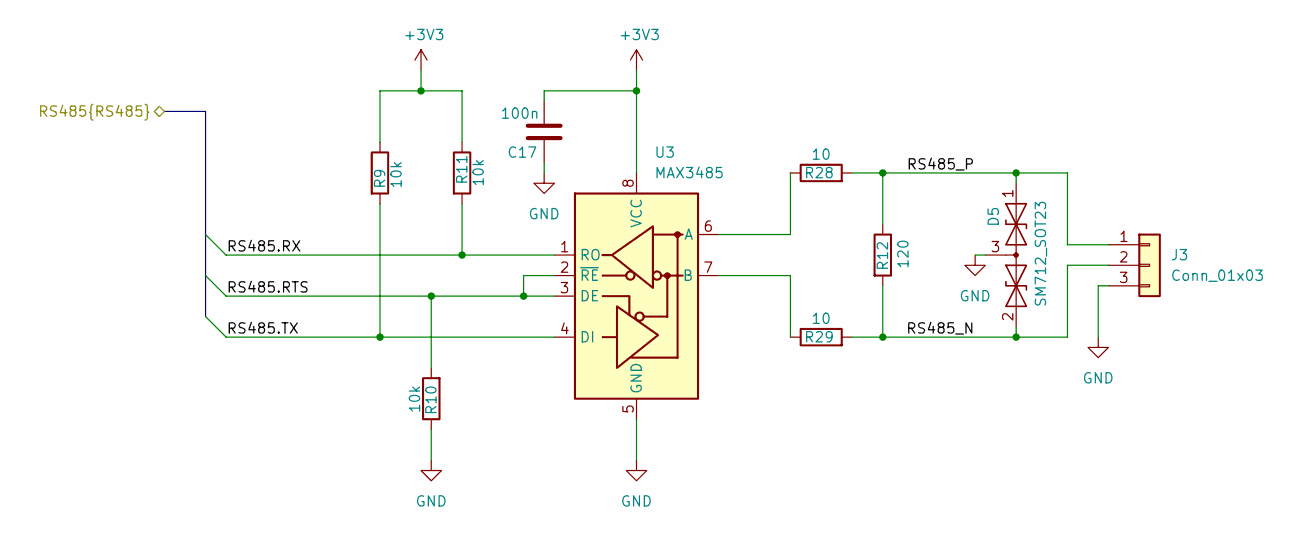
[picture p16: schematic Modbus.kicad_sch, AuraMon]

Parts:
C17: 100n; C_0402_1005Metric; MPN CL05B104KO5NNNC; JLCPCB Part # C1525
D5: SM712_SOT23; SOT-23; MPN CDSOT23-SM712; JLCPCB Part # C404012
J3: Conn_01x03; JST_PH_S3B-PH-K_1x03_P2.00mm_Horizontal; MPN S3B-PH-K-S(LF)(SN); JLCPCB Part # C157929
R9, R10, R11: 10k; R_0402_1005Metric; MPN RC0402JR-0710KL; JLCPCB Part # C60489
R12: 120; R_0402_1005Metric; MPN RC0402FR-07120RL; JLCPCB Part # C114758
R28, R29: 10; R_0402_1005Metric; MPN RC0402FR-0710RL; JLCPCB Part # C138066
U3: MAX3485; SOIC-8; MPN SN65HVD75DR; JLCPCB Part # C57928

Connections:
+3V3: C17.2, R9.1, R11.1, U3.8 (VCC); also elsewhere on the board
/MCU/RS485.RTS: R10.2, U3.2 (~RE), U3.3 (DE); also elsewhere on the board
/MCU/RS485.RX: R11.2, U3.1 (RO); also elsewhere on the board
/MCU/RS485.TX: R9.2, U3.4 (DI); also elsewhere on the board
/Modbus/RS485_N: D5.2 (A2), J3.2, R12.2, R29.2
/Modbus/RS485_P: D5.1 (A1), J3.1, R12.1, R28.2
GND: C17.1, D5.3 (common), J3.3, R10.1, U3.5 (GND); also elsewhere on the board
unnamed: R28.1, U3.6 (A)
unnamed: R29.1, U3.7 (B)

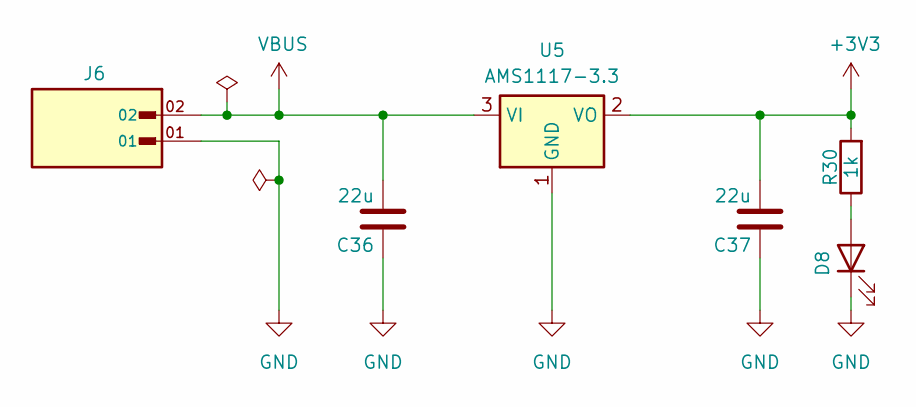
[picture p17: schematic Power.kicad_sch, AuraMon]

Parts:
C36, C37: 22u; C_0603_1608Metric; MPN CL10A226MQ8NRNC; JLCPCB Part # C59461
D8: LED; LED_0603_1608Metric; MPN LTST-C191KGKT; JLCPCB Part # C125098
J6: 1881448; PHOENIX_1881448; MPN 1881448; JLCPCB Part # C5480444
R30: 1k; R_0402_1005Metric; MPN RC0402FR-071KL; JLCPCB Part # C106235
U5: AMS1117-3.3; SOT-223-3_TabPin2; MPN AMS1117-3.3; JLCPCB Part # C347222

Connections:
+3V3: C37.2, R30.2, U5.2 (VO); also elsewhere on the board
GND: C36.1, C37.1, D8.1 (K), J6.01, U5.1 (GND); also elsewhere on the board
unnamed: D8.2 (A), R30.1
VBUS: C36.2, J6.02, U5.3 (VI); also elsewhere on the board

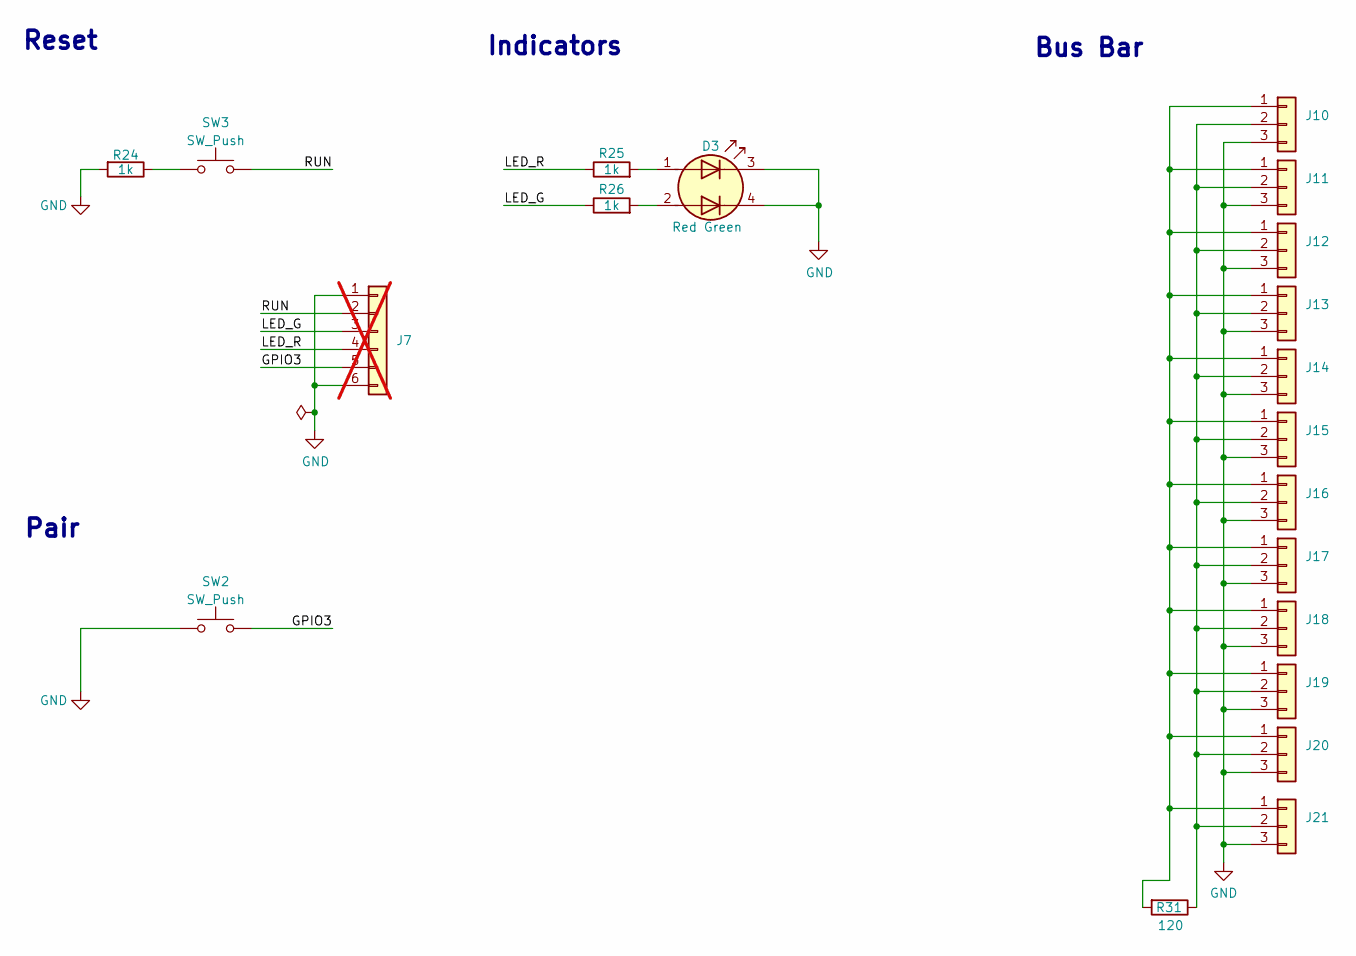
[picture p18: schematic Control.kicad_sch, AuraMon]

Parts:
D3: Red Green; LED_LiteOn_LTST-C295K_1.6x0.8mm; MPN LTST-C295KGKRKT; JLCPCB Part # C364568
J7: Conn_01x06; JST_SH_BM06B-SRSS-TB_1x06-1MP_P1.00mm_Vertical; MPN BM06B-SRSS-TB(LF)(SN); JLCPCB Part # C160392; not fitted
J10, J11, J12, J13, J14, J15, J16, J17, J18, J19, J20, J21: Conn_01x03; JST_PH_B3B-PH-K_1x03_P2.00mm_Vertical; MPN B3B-PH-K-S(LF)(SN); JLCPCB Part # C131339
R24, R25, R26: 1k; R_0402_1005Metric; MPN RC0402FR-071KL; JLCPCB Part # C106235
R31: 120; R_0402_1005Metric; MPN RC0402FR-07120RL; JLCPCB Part # C114758
SW2, SW3: SW_Push; PTS815SJM250SMTRLFS; MPN SKRPACE010; JLCPCB Part # C139797

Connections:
/Control/GPIO3: J7.5, SW2.2
/Control/LED_G: J7.3, R26.1
/Control/LED_R: J7.4, R25.1
/Control/RUN: J7.2, SW3.2
GND: D3.3 (K1), D3.4 (K2), J7.1, J7.6, J10.3, J11.3, J12.3, J13.3, J14.3, J15.3, J16.3, J17.3, J18.3, J19.3, J20.3, J21.3, R24.2, SW2.1; also elsewhere on the board
unnamed: D3.1 (A1), R25.2
unnamed: D3.2 (A2), R26.2
unnamed: J10.1, J11.1, J12.1, J13.1, J14.1, J15.1, J16.1, J17.1, J18.1, J19.1, J20.1, J21.1, R31.2
unnamed: J10.2, J11.2, J12.2, J13.2, J14.2, J15.2, J16.2, J17.2, J18.2, J19.2, J20.2, J21.2, R31.1
unnamed: R24.1, SW3.1

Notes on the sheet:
Indicators
Bus Bar
Pair
Reset

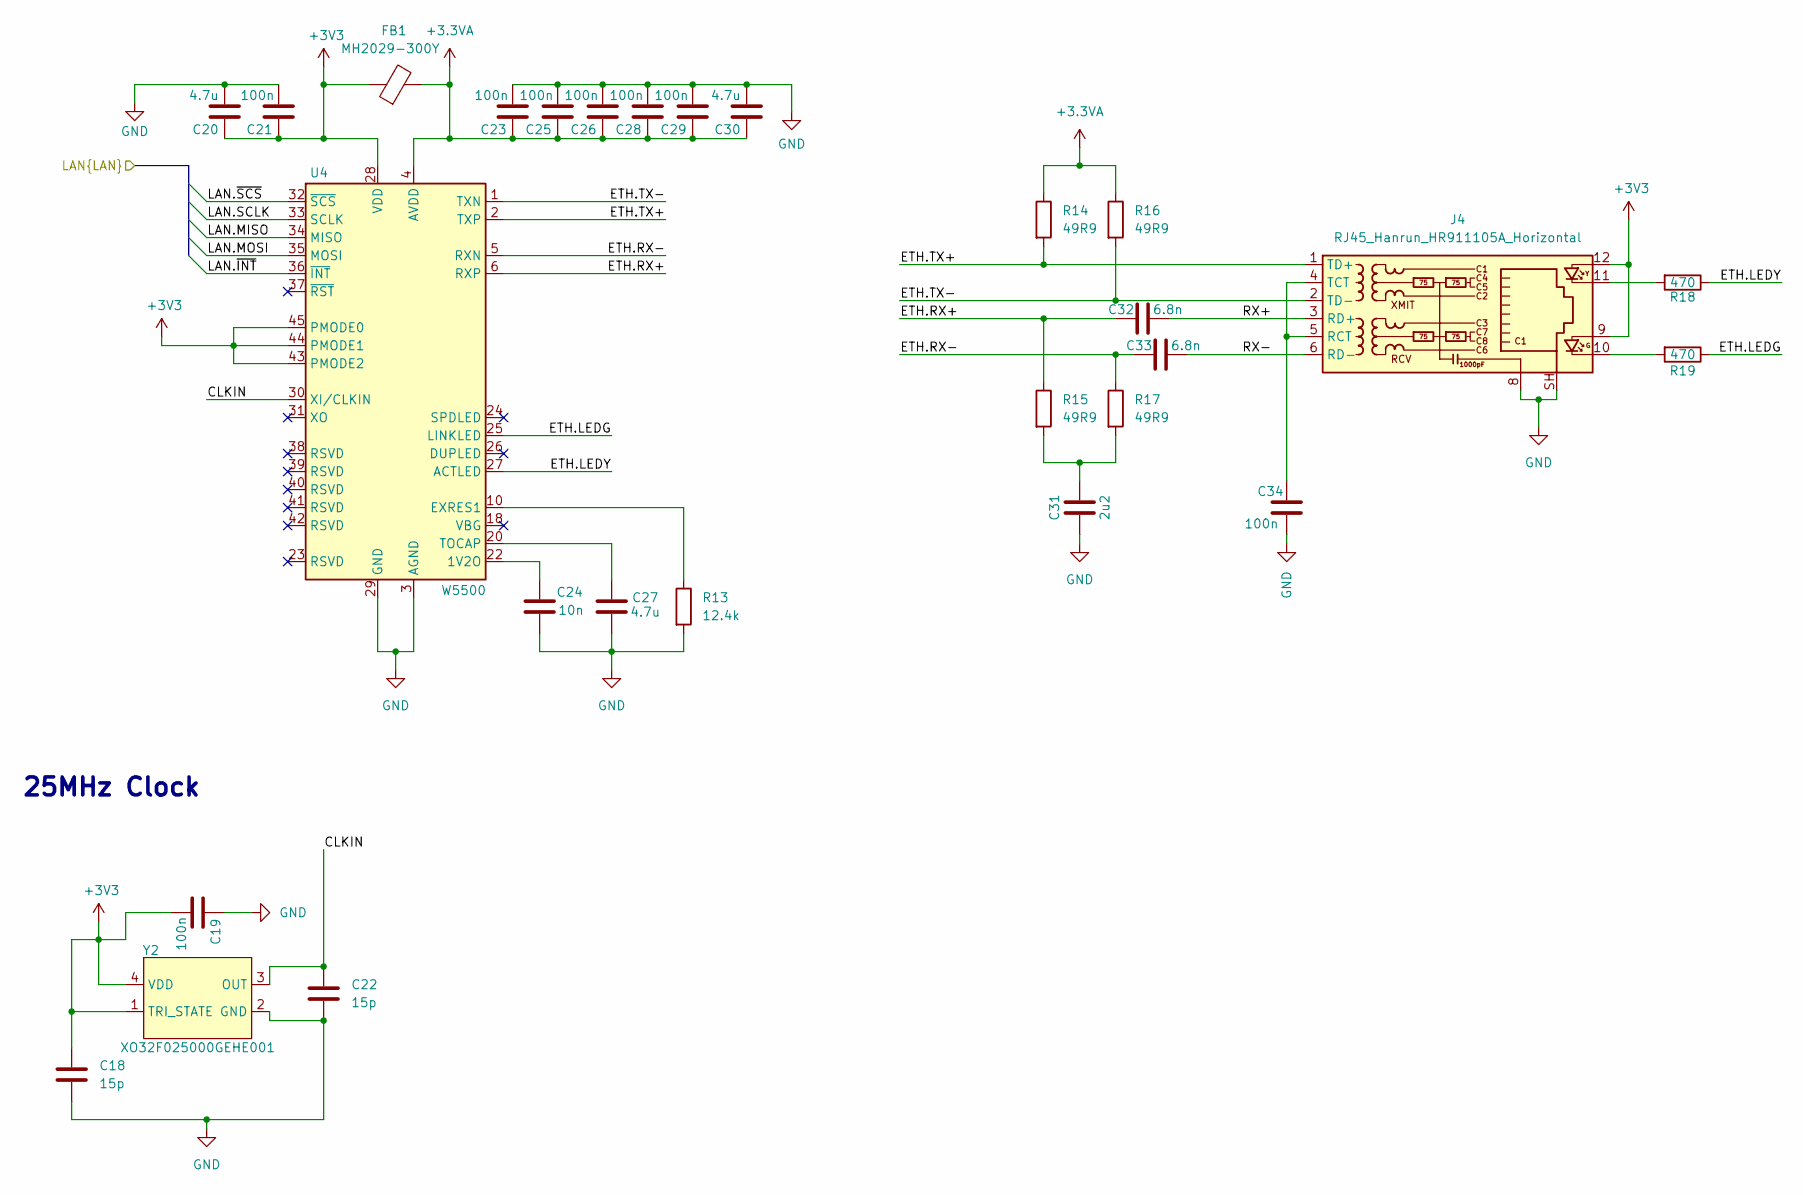
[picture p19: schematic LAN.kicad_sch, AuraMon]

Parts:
C18, C22: 15p; C_0402_1005Metric; MPN CL05C150JB5NNNC; JLCPCB Part # C86285
C19, C21, C23, C25, C26, C28, C29, C34: 100n; C_0402_1005Metric; MPN CL05B104KO5NNNC; JLCPCB Part # C1525
C20, C27, C30: 4.7u; C_0402_1005Metric; MPN CL05A475MO5NUNC; JLCPCB Part # C318563
C24: 10n; C_0402_1005Metric; MPN CL05B103KB5NNNC; JLCPCB Part # C15195
C31: 2u2; C_0402_1005Metric; MPN CL05A225KA5NUNC; JLCPCB Part # C307418
C32, C33: 6.8n; C_0603_1608Metric; MPN CC0603KRX7R0BB682; JLCPCB Part # C576854
FB1: MH2029-300Y; L0805; MPN MH2029-300Y; JLCPCB Part # C840593
J4: RJ45_Hanrun_HR911105A_Horizontal; MPN HR911105A; JLCPCB Part # C12074
R13: 12.4k; R_0603_1608Metric; MPN RC0603FR-0712K4L; JLCPCB Part # C137798
R14, R15, R16, R17: 49R9; R_0603_1608Metric; MPN RC0603FR-0749R9L; JLCPCB Part # C114625
R18, R19: 470; R_0402_1005Metric; MPN RC0402FR-7W470RL; JLCPCB Part # C606172
U4: W5500; LQFP-48_7x7mm_P0.5mm; MPN W5500; JLCPCB Part # C32843
Y2: XO32F025000GEHE001; Crystal_SMD_3225-4Pin_3.2x2.5mm; MPN XO32F025000GEHE001; JLCPCB Part # C20607963

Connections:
+3.3VA: C23.1, C25.1, C26.1, C28.1, C29.1, C30.1, FB1.2, R14.1, R16.1, U4.4 (AVDD), U4.8 (AVDD), U4.11 (AVDD), U4.15 (AVDD), U4.17 (AVDD), U4.21 (AVDD)
+3V3: C18.2, C19.2, C20.1, C21.1, FB1.1, J4.9, J4.12, U4.28 (VDD), U4.43 (PMODE2), U4.44 (PMODE1), U4.45 (PMODE0), Y2.1 (TRI_STATE), Y2.4 (VDD); also elsewhere on the board
/LAN/CLKIN: C22.1, U4.30 (XI/CLKIN), Y2.3 (OUT)
/LAN/ETH.LEDG: R19.1, U4.25 (LINKLED)
/LAN/ETH.LEDY: R18.1, U4.27 (ACTLED)
/LAN/ETH.RX+: C32.1, R15.1, U4.6 (RXP)
/LAN/ETH.RX-: C33.1, R17.1, U4.5 (RXN)
/LAN/ETH.TX+: J4.1 (TD+), R14.2, U4.2 (TXP)
/LAN/ETH.TX-: J4.2 (TD-), R16.2, U4.1 (TXN)
/LAN/LAN.MISO: U4.34 (MISO); also elsewhere on the board
/LAN/LAN.MOSI: U4.35 (MOSI); also elsewhere on the board
/LAN/LAN.SCLK: U4.33 (SCLK); also elsewhere on the board
/LAN/LAN.~INT: U4.36 (~INT); also elsewhere on the board
/LAN/LAN.~SCS: U4.32 (~SCS); also elsewhere on the board
/LAN/RX+: C32.2, J4.3 (RD+)
/LAN/RX-: C33.2, J4.6 (RD-)
GND: C18.1, C19.1, C20.2, C21.2, C22.2, C23.2, C24.2, C25.2, C26.2, C27.2, C28.2, C29.2, C30.2, C31.2, C34.2, J4.8, J4.SH, R13.2, U4.3 (AGND), U4.9 (AGND), U4.14 (AGND), U4.16 (AGND), U4.19 (AGND), U4.29 (GND), U4.48 (AGND), Y2.2 (GND); also elsewhere on the board
unnamed: C31.1, R15.2, R17.2
unnamed: J4.10, R19.2
unnamed: J4.11, R18.2
unnamed: C34.1, J4.4 (TCT), J4.5 (RCT)
unnamed: C24.1, U4.22 (1V2O)
unnamed: R13.1, U4.10 (EXRES1)
unnamed: C27.1, U4.20 (TOCAP)

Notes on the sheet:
25MHz Clock

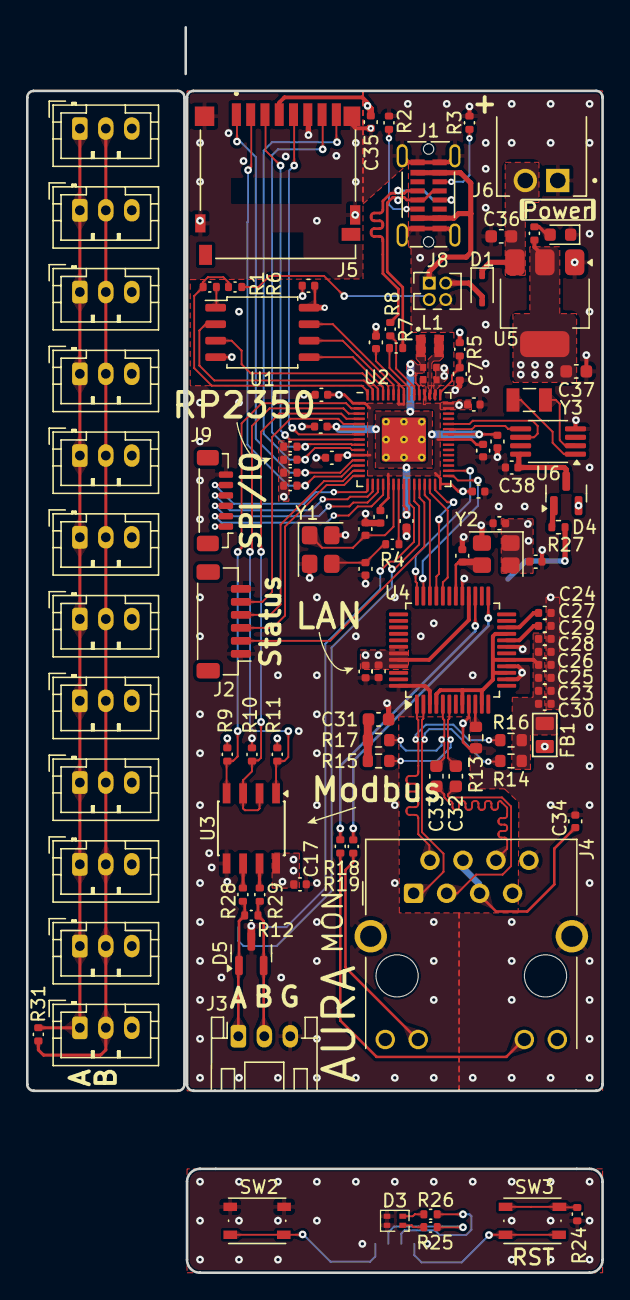
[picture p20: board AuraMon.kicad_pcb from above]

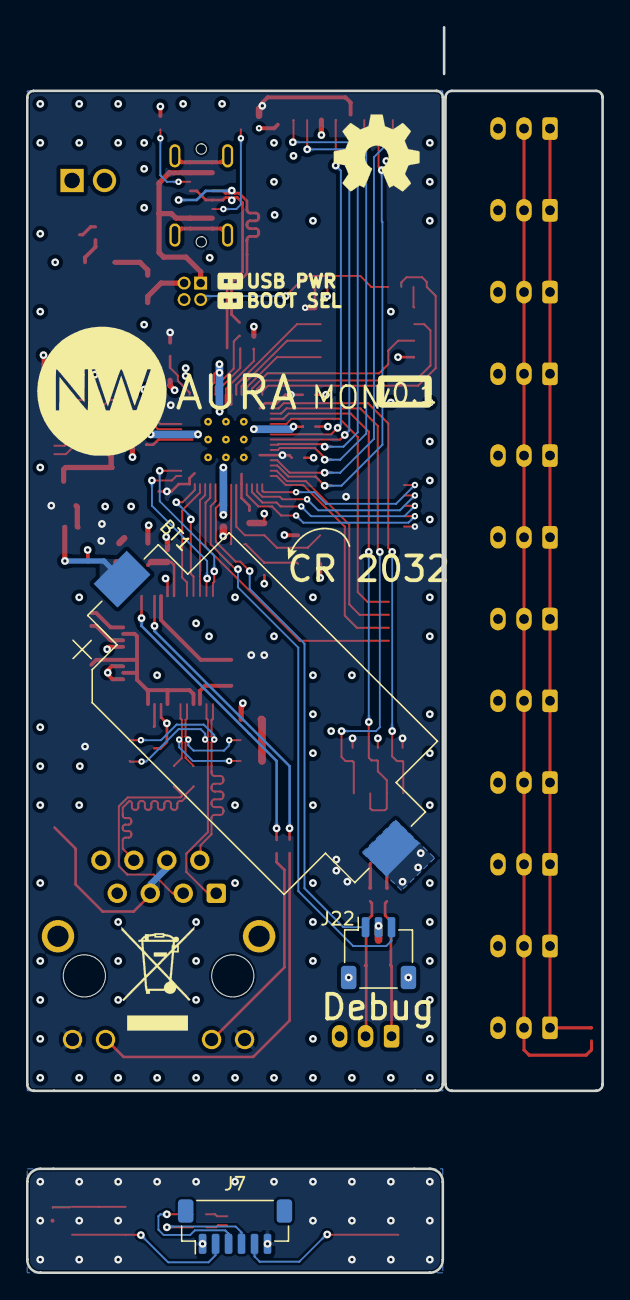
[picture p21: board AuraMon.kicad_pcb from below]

Board: 4 copper layers, 44.3 x 95.9 mm, 117 parts (7 on the bottom side), 87 nets.

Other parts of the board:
G2, G2#2: LOGO; Arrow2
G3: LOGO; Arrow3
G4: LOGO; Arrow1
G10: LOGO; Logo
OSHW: OSHW-Symbol_6.7x6mm_SilkScreen
SS3: WEEE-Logo_5.6x8mm_SilkScreen

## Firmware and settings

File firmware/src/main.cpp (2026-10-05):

//
// Created by Nicholas Wiersma on 2026/03/19.
//

#include "auramon.h"

// Disable SysTick on core 1 to free up the timer for Ticker.
bool core1_disable_systick = true;
// Use a separate stack for core 1 to avoid clashes with core 0.
bool core1_separate_stack = true;

time_t            startTime;
Ticker            ledTimer;
volatile LEDColor ledState;

mutex_t sdMu;
SdFs    sd;

Logger msgLog;

PCF85063A rtc;
bool      rtcRunning = false;

Wiznet5500lwIP eth(PIN_SPI0_SS, SPI, ETH_INT);
NetworkConfig  netCfg;

mutex_t             deviceDataMu;
InputDeviceData *   deviceData[MAX_DEVICES] = {};
mutex_t             deviceActionMu;
DeviceActionRequest deviceActionControl = {DeviceActionType::None, 0};
DeviceActionRequest deviceActionData = {DeviceActionType::None, 0};
mutex_t             deviceInfoMu;
volatile bool       devicesChanged;
InputDeviceInfo *   deviceInfos[MAX_DEVICES] = {};
InputDevice *       devices[MAX_DEVICES] = {};
DataLog             datalog;

promMetrics metrics;

mutex_t          uploaderConfigMu;
volatile bool    uploadersChanged;
UploaderConfig * uploaderConfigs[MAX_UPLOADERS] = {};

ModbusRTUMaster modbus(Serial1, RS485_DE);

WebServer server(80);

taskQueue c0Queue = {};
taskQueue c1Queue = {};

void blinkLED();
void handleButtonPress();
void waitForSerial();

void setup() {
    pinMode(LED_RED, OUTPUT);
    pinMode(LED_GREEN, OUTPUT);
    digitalWrite(LED_RED, HIGH);
    digitalWrite(LED_GREEN, HIGH);

    pinMode(BUTTON_PIN, INPUT_PULLUP);

    waitForSerial();

    LOGD("Booting");

    mutex_init(&sdMu);
    if (!sd.begin(SD_CONFIG)) {
        Serial.println("Could not initialize SD Card. Halting");
        sd.initErrorPrint(&Serial);

        digitalWrite(LED_GREEN, LOW);
        while (1) { delay(1000); }
    }

    LOGI("Firmware version: %s", AURAMON_VERSION);
    restartReasonLog();
    LOGI("SD Card initialised");

    rtc.begin(&Wire1);

    LOGI("RTC initialised");

    if (rtc.isRunning()) {
        if (rtc.lostPower()) {
            LOGI("RTC lost power. Please check your battery");
        }
        time_t  ts = rtc.now();
        timeval tv;
        tv.tv_sec = ts;
        tv.tv_usec = 0;
        settimeofday(&tv, nullptr);
        rtcRunning = true;
        LOGI("RTC is running: Unix time %" PRId64, (int64_t)ts);
    } else {
        LOGI("RTC not running");
    }
    startTime = time(nullptr);

    mutex_init(&deviceDataMu);
    mutex_init(&deviceActionMu);
    mutex_init(&deviceInfoMu);
    mutex_init(&uploaderConfigMu);

    if (auto err = loadConfig(); err) {
        LOGI("Could not load config from SD Card: %s", err.Error());
    } else {
        LOGI("Config loaded from SD Card");
    }
    syncDeviceInfo();
    syncUploaderInstances(true);

    eth.setSPISpeed(ETH_FREQ);
    eth.hostname(netCfg.hostname);
    if (netCfg.hasIP()) {
        eth.config(
            ipaddr_addr(netCfg.ip.c_str()),
            ipaddr_addr(netCfg.gateway.c_str()),
            ipaddr_addr(netCfg.mask.c_str()),
            ipaddr_addr(netCfg.dns.c_str()),
            0);
    }
    if (!eth.begin(mac)) {
        LOGE("No wired Ethernet hardware detected.");

        digitalWrite(LED_GREEN, LOW);
        while (true) { delay(1000); }
    }

    LOGI("Ethernet initialised");

    if (!datalog.begin()) {
        LOGE("Datalog could not be opened.");

        digitalWrite(LED_GREEN, LOW);
        while (true) { delay(1000); }
    }

    LOGI("Datalog initialised");

    Serial1.begin(RS485_BAUDRATE);
    modbus.begin(RS485_BAUDRATE);
    modbus.setTimeout(60);

    LOGI("Modbus initialised");

    setupAPI();
    server.begin();

    c0Queue.add(timeSync, 5);
    c0Queue.add(checkEthernet, 5);
    c0Queue.add(syncState, 4);
    c0Queue.add(syncUploaders, 3);
    c0Queue.add(writeLogData, 6);

    c1Queue.add(logData, 7);
    c1Queue.add(syncDevices, 6);
    c1Queue.add(deviceActionTask, 5);

    syncState(nullptr);
    ledTimer.attach(1, blinkLED);

    // Indicate that setup is complete and core 1 can start.
    rp2040.fifo.push(1);
}

void loop() {
    server.handleClient();
    handleButtonPress();

    if (!c0Queue.runNextTask()) {
        delay(10);
    }
}

void setup1() {
    // Wait for core 0 to indicate that setup is complete before starting.
    rp2040.fifo.pop();

    // Set the initial monotonic ts so we know
    // how long it took before the first log write.
    initLogData();

    rp2040.wdt_begin(1000);
}

void loop1() {
    const unsigned long start = millis();

    collect();

    // Run any available tasks until collection is ready.
    while (millis() - start < 1000) {
        if (!c1Queue.runNextTask()) {
            delay(10);
        }

        rp2040.wdt_reset();
    }
}

void safeReboot() {
    // Write out any records still waiting to be logged.
    drainLogData();

    // Drain the data log.
    datalog.end();

    // Block any remaining SD operations and cleanly terminate the
    // SDIO peripheral before resetting.
    mutex_enter_blocking(&sdMu);
    sd.end();

    rp2040.reboot();
}

void blinkLED() {
    static bool on = false;
    switch (ledState) {
        case LEDColor::Red:
            digitalWrite(LED_RED, on ? HIGH : LOW);
            digitalWrite(LED_GREEN, LOW);
            break;
        case LEDColor::Green:
            digitalWrite(LED_RED, LOW);
            digitalWrite(LED_GREEN, on ? HIGH : LOW);
            break;
        case LEDColor::Orange:
            digitalWrite(LED_RED, on ? HIGH : LOW);
            digitalWrite(LED_GREEN, on ? HIGH : LOW);
            break;
    }
    on = !on;
}

void handleButtonPress() {
    static int           lastReading = HIGH;
    static int           stableState = HIGH;
    static unsigned long lastChangeMs = 0;

    int reading = digitalRead(BUTTON_PIN);
    if (reading != lastReading) {
        lastChangeMs = millis();
        lastReading = reading;
    }

    if (millis() - lastChangeMs < BUTTON_DEBOUNCE_MS) {
        return;
    }

    if (stableState == reading) {
        return;
    }

    stableState = reading;
    if (stableState == HIGH) {
        c0Queue.add(addDeviceFromButton, 6);
    }
}

void waitForSerial() {
    if constexpr (WAIT_FOR_SERIAL) {
        while (!Serial) { delay(100); }
    }
}

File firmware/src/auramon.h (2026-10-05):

//
// Created by Nicholas Wiersma on 2025/09/05.
//

#pragma once

#include <Arduino.h>
#include <pico/mutex.h>
#include <errors.h>
#include <SdFat.h>
#include <W5500lwIP.h>
#include <ModbusRTUMaster.h>
#include <Wire.h>
#include <PCF85063A.h>
#include <WebServer.h>
#include <ArduinoJSON.h>
#include <Ticker.h>

#include "Logger.h"
#include "crash_handler.h"
#include "config.h"
#include "ethernet.h"
#include "data_log.h"
#include "log_queue.h"
#include "task.h"
#include "modbus.h"
#include "api.h"
#include "device.h"
#include "metrics.h"
#include "uploader/uploader_registry.h"
#include "version.h"

#define WAIT_FOR_SERIAL 0

#define MS_PER_HOUR 3600000UL

#define MESSAGE_LOG_PATH "aura-mon/log.txt"
#define CONFIG_LOG_PATH     "aura-mon/config.json"
#define CONFIG_LOG_TMP_PATH "aura-mon/config.json.tmp"
#define DATA_LOG_PATH    "aura-mon/data.log"

#define LED_RED 10
#define LED_GREEN 11

#define BUTTON_PIN 3

#define ETH_INT  20
#define ETH_FREQ 40000000 // 40MHz

#define SD_CLK 4
#define SD_CMD 5
#define SD_DAT0 6 // DAT[1:3] - 7:9
#define SD_CLKDIV 2.0 // Run below 25MHz
#define SD_CONFIG SdioConfig(SD_CLK, SD_CMD, SD_DAT0, SD_CLKDIV)

#define RS485_TX 0
#define RS485_RX 1
#define RS485_DE 2
#define RS485_BAUDRATE 38400

#define BUTTON_DEBOUNCE_MS 200

#define QUEUE_FULL_WATCHDOG_MS 5000

enum LEDColor { Red, Orange, Green };

inline byte mac[] = {0xDE, 0xAD, 0xBE, 0xEF, 0xFE, 0xEE};

extern time_t            startTime;
extern Ticker            ledTimer;
extern volatile LEDColor ledState;

extern Wiznet5500lwIP eth;
extern NetworkConfig  netCfg;

extern PCF85063A rtc;
extern bool      rtcRunning;

extern mutex_t sdMu;
extern SdFs    sd;

extern ModbusRTUMaster modbus;

extern WebServer server;

#define MAX_DEVICES 15
extern mutex_t             deviceDataMu;
extern InputDeviceData *   deviceData[MAX_DEVICES];
extern mutex_t             deviceActionMu;
extern DeviceActionRequest deviceActionControl;
extern DeviceActionRequest deviceActionData;
extern mutex_t             deviceInfoMu;
extern volatile bool       devicesChanged;
extern InputDeviceInfo *   deviceInfos[MAX_DEVICES];
extern InputDevice *       devices[MAX_DEVICES];

extern DataLog datalog;

extern promMetrics metrics;

#define MAX_UPLOADERS 4
extern mutex_t          uploaderConfigMu;
extern volatile bool    uploadersChanged;
extern UploaderConfig * uploaderConfigs[MAX_UPLOADERS];

extern taskQueue c0Queue;

uint32_t timeSync(void *param);
uint32_t checkEthernet(void *param);
void     initLogData();
uint32_t logData(void *param);
uint32_t writeLogData(void *param);
void     drainLogData();
void     syncDeviceInfo();
uint32_t syncDevices(void *param);
uint32_t syncState(void *param);
uint32_t deviceActionTask(void *param);
uint32_t addDeviceFromButton(void *param);

void collect();
void safeReboot();

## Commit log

2025-09-27 feat: initial PCB (#1)
    [AuraMon.kicad_pcb, AuraMon.kicad_sch, Control.kicad_sch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]
2025-09-27 fix: unavailable components
    [AuraMon.kicad_pcb, Control.kicad_sch, SDCard.kicad_sch]
2025-09-28 feat: replace status LED
    [AuraMon.kicad_pcb, Control.kicad_sch]
2025-10-20 fix: status LED resistor value
    [AuraMon.kicad_pcb, Control.kicad_sch, Power.kicad_sch]
2025-11-12 feat: add SWD footprint
    [AuraMon.kicad_pcb, LAN.kicad_sch, MCU.kicad_sch]
2026-01-16 chore: add readme (#2)
    [Base Left.stl, Base Right.stl, Clip.stl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]
2026-02-17 feat: update dark mode theme (#7)
    * feat: update dark mode theme
    * fix: drawer close button
2026-02-17 fix: UI drawer button
2026-02-19 feat: track datalog cache hits
2026-02-19 feat: add reboot endpoint (#10)
    * feat: add device reboot
    * feat: refactor icons
2026-03-08 fix: minor issues and improvements (#12)
    [main.cpp]
2026-03-18 feat: add crash handler and restart reason (#16)
    [auramon.h, main.cpp]
2026-04-05 fix: log for ts (#29)
    [main.cpp]
2026-04-06 feat: fix memory leak (#30)
    [main.cpp]
2026-04-06 fix: cleanly close SD card on reboot (#34)
    [auramon.h, main.cpp]
2026-04-07 chore: minor grafana board updates
2026-08-14 fix: update sdfat (#40)
    [auramon.h, main.cpp]
2026-08-15 fix: record write queue (#41)
    [auramon.h, main.cpp]
2026-09-02 fix: make status led more reliable (#42)

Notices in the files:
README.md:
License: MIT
